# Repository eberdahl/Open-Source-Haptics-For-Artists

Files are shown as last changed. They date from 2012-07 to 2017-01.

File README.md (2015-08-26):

Open-Source-Haptics-For-Artists
-------------------------------
This website provides a venue for users to share open-source software and hardware haptic technology with one another. While the focus is primarily on artistic applications, we believe that mutual collaboration can help the field of haptics progress most rapidly in art, science, and technology. 

This git repository has been created via a collaboration between the Technical University of Berlin, the Cardiff School of Art & Design, and Stanford University.  If you develop some nice contributions, please let us know, and we would be happy to incorporate them.

Current maintainers:
Edgar Berdahl (eberdahl@ccrma.stanford.edu)
and
Alexandros Kontogeorgakopoulos (akontogeorgakopoulos@cardiffmet.ac.uk)

Main website:
http://www.openhaptics.org/

To use OSHA, install git and then run the following command:

git clone --recursive https://github.com/eberdahl/Open-Source-Haptics-For-Artists.git

cd Open-Source-Haptics-For-Artists

To update this repository, run the following from the root directory:

git pull

git submodule update

In general, please use the Google group for asking questions:
https://groups.google.com/group/open-source-haptics-for-artists

I have decided to officially support the Max/MSP objects and the Synth-A-Modeler objects, once I deliver them.  I STRONGLY RECOMMEND USING MAX/MSP OR SYNTH-A-MODELER.  However, I understand that people might be interested in using the older pd or Chai3D code, so I am including the source for them as starter code.

Notes on software
-----------------
- Currently the Max/MSP support is the most fleshed out, including testing the concept of using capacitive sensing to enable or disable the force feedback.  To use the Max/MSP patches, you will to put the palette folder in the path.
!!!**  Remember to set the "Signal Vector Size" to 1  **!!!

Notes on hardware
-----------------
By default the motor controller sets up 
- D4: Direction control of Motor A 
- D5: PWM speed control of Motor A 
- D6: PWM speed control of Motor B 
- D7: Direction control of Motor B 
- A0: Current sense of Motor A 
- A1: Current sense of Motor B 

So pin D5 and D6 on Arduino are ATMega328 pins correspond to
D5 --> PD5(T1)
D6 --> PD6(AIN0)

Best,
Edgar Berdahl
March, 2012 and updated July, 2012 and October, 2012

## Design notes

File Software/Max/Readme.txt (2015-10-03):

Max/MSP support is implemented via the HSP ("Haptic Signal Processing") package

Contributors: Edgar Berdahl and Alexandros Kontogeorgakopoulos

For Max/MSP 5, 6 and 7.

It has been tested on Mac OS X with Intel processors.  The FireFader works in Windows (but to use the NovInt Falcon device in Windows, someone would need to recompile the external object "np_nifalcon.mxo").

VERY IMPORTANT
--------------
1. Add the "palette" folder to the paths for Max/MSP 5, and then try out the examples in the models folder.
2. Set the "Signal Vector Size" to 1 in the DSP Settings.
3. Set the "Event Interval (ms)" to 1 and the "Scheduler Interval (ms)" to 1 in the Preferences.

MAKE SURE THAT YOU’RE OPENING THE CORRECT HAPTIC DEVICE
-------------------------------------------------------
1. First make sure that the FireFader (or whatever haptic device you want to use) is unplugged.
2. Open the FireFader~.maxpat file in Max.
3. Click on the ‘print’ message and look in the Max window to see what letter Max is associating with each serial device that Max is finding.  The haptic device that you want will not be here.
4. Close FireFader~.maxpat.
5. Wait five seconds, plug in the haptic device and then open FireFader~.maxpat again, and then wait fifteen seconds.
6. Click on the ‘print’ message to list what letter Max is associating with each serial device that Max is finding.  The new serial port entry corresponds to your device.
7. Make sure that the second argument to the ‘serial’ object in FireFader~.maxpat matches the letter of the device.
8. By this point, you should also see some meaningful output inside the number boxes below representing the ‘position’ of the device.

You will need to follow some similar procedure in concept to this to open the Falcon.

Note: If the FireFader is plugged in to a Mac before the Mac is booted up, it will likely show up with a different letter (e.g. ‘a’) once the computer boots up.  This can be fixed by unplugging it, waiting 5 seconds, plugging it in again, and waiting 15 seconds.

TROUBLESHOOTING
---------------
If it isn’t working the way you expect, make sure that you precisely followed each of the above steps.  Then, if there are still difficulties (such as models not feeling the way that you think they should feel), close all other applications, reboot the computer, and run only Max.  Finally, it can also help (particularly if there are some animated GUI objects in the Max patch) to minimize the Max patch so that Max isn't running any drawing routines.  The reason for this is that the graphics events are running at the same priority level as the serial object.

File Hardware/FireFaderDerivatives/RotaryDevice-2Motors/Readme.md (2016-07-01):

This design is the same as the FireFader except that in place of fader A, a rotary motor with rotary encoder is connected.  In place of fader B, a second rotary motor with rotary encoder is connected.  For those motors, we have the same power connections as with the motorized fader.

This is how it works using two motors:

We could use one hardware interrupt per motor.  In this case, we will have to rewrite the interrupt handlers CountA() and CountB() to do the logic for each motor separately.  In that case, whenever an interrupt is triggered, we need to manually check the value of the other phase (connected to some other digital input pin that doesn’t support hardware interrupts) and then figure out how to do the right state machine logic.

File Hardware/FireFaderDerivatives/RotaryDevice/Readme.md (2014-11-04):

This design is the same as the FireFader except that in place of fader A, a rotary motor with rotary encoder is connected.  For that motor, we have the same power connections as with the motorized fader.

However, the sensing works differently.  Instead of connecting an analog voltage to pin A2, we instead use two digital inputs that are 90° out of phase with each other.  “Phase A” of the rotary encoder is connected by a white wire to pin D2, which supports hardware interrupts.  “Phase B” of the rotary encoder is connected by a green wire to pin D3, which also supports hardware interrupts.  By typing a hardware interrupt to each of the encoder phases, we can get the maximum resolution of the measurement.  Power (i.e. 5V) and ground (blue wire) are also connected to the encoder to power its circuitry.

In summary, for the rotary motor we have the following:

blue-ground

white-channel A

red-5V

green-channel B

I recommend using rotary motors that have at least 400 counts per revolution to get the most accurate sensing.  In the current project, I’m using motors that have about 1000 counts per revolution.  See the datasheets stored inside the directory Encoder-Datasheets for information on some common rotary encoders such as HEDL 5540 and HEDS 5540.

To hook up a second rotary motor:

* We could use one hardware interrupt per motor.  In this case, we will have to rewrite the interrupt handlers CountA() and CountB() to do the logic for each motor separately.  In that case, whenever an interrupt is triggered, we need to manually check the value of the other phase (connected to some other digital input pin that doesn’t support hardware interrupts) and then figure out how to do the right state machine logic.

* Or we could try to connect the second motor’s encoder phases instead to digital inputs 0 and 1, which also support hardware interrupts.  This will give us higher resolution measurements overall; however, I believe that it will interfere with the USB communication, so try it at your own risk!  You may not be able to connect it to the Max models at all!

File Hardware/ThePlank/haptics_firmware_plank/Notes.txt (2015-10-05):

To use The Plank with the Open-Source-Haptics-For-Artists repository, it's necessary to have a way
to disable the force feedback if the user isn't touching the device.  This could be accomplished
by using the FSR as a sensor to check if the user is touching the handle; however, then further 
modifications would need to be made to this firmware and the circuit.  Instead, I recommend 
adding a capacitive sensor to the device handle.  This way, the device can be played with a light touch.

This can be achieved by:
• taking a piece of copper tape and soldering a stranded wire to it (use some solder flux to 
  make this easier)
• strip the other end of the wire and tin it if using a breadboard
• use a piece of (electrically nonconducting) double-stick tape to attach the piece of copper tape
  to the device handle
• build the circuit as shown in Figure 5 of the Computer Music Journal article
  "The FireFader: Simple, Open-Source, and Reconfigurable Haptic Force Feedback for Musicians"
  replacing "Motor A."  Instead of connecting the 2nd pin of the potentiometer to Arduino pin A2,
  connect the voltage output of the Hall-effect sensor to Arduino pin A2.
• Repeat the same procedure analogously for a second Plank motor as "Motor B."

USE THE ARDUINO MICRO FOR BUILDING THIS WITH THE MOTOR DRIVER http://www.gravitech.us/2mwfecoadfor.html, ALSO AVAILABLE THROUGH MOUSER.

// Anyone trying to use The Plank with Open-Source-Haptics-For-Artists should first try the 
// Synth-A-Modeler models, which are compatible with this firmware.  To do this, run 
// 'make jackqt' inside the SaM subdirectory of the part of the repo
// https://github.com/eberdahl/Open-Source-Haptics-For-Artists/tree/master/Software/Synth-A-Modeler
// and visit https://ccrma.stanford.edu/wiki/SynthAModelerFireFaderLab for additional instructions
// to set that up.
// 
// After getting those working, then try the models in Max using the FireFader~ object to interface
// with the firmware--see
// https://github.com/eberdahl/Open-Source-Haptics-For-Artists/blob/master/Software/Max/Readme.txt

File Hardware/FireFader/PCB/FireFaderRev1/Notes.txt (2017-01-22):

The FireFader is a haptic device, whose electronics can be easily realized using a simple breadboard.  In our opinion, the PCB is not really part of the original concept of the FireFader.  However, some folks have been asking for the PCB design, with the potential for creating other derivative designs, which is a nice possibility, so the PCB version is posted here as well.

This design is specifically for the ALPS RSA0N11M9A06.  This specific part might no longer be available new; however, new ALPS parts with a very similar part number (that to us are indistinguishable) appear to be drop-in replacements.

Additional notes:
• The schematic part symbol in the .brd file is not accurate; however, the manufactured board has verified as working.
• There might potentially be other issues with the ALPS-motorfader.lbr which was found on the Internet and whose footprint had to be modified in order to generate correct Gerber files.

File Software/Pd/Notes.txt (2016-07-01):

PD IS NOT OFFICIALLY SUPPORTED !!!!!

If there are any compiled SaM patches here, in order to use them, you will have to add two_examples-FireFader to the pd path.

The pure data patches are not currently maintained for these reasons:
 ¥ The Max/MSP scheduler is able to run a little bit faster than the Pd scheduler, so the feedback control works a little bit better.
 ¥ It's harder to build physical models directly in pd because pd requires you to manually insert all of the single sample delays separately (so the patches don't look as nice).
 ¥ We don't have a particularly nice collection of models that are in good shape to be presented.

If you really need to use pd, drop us a line and we will see what can be done about it!

Cheers,
Edgar Berdahl

PS. In pd, try adding the following to the startup flags to decrease the delay for haptics:
-rt -sleepgrain 1
(or maybe -rt -sleepgrain 2 if the previous crashes pd on your machine)

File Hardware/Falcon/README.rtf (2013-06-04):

Although the Falcon is not an open-source hardware device, it has been hacked. Thanks to Kyle Machulis for taking the lead on writing the driver for it! The driver source is included here for those who wish to compile it. However, a compiled version of the Max/MSP 5 external for OS X (Intel) "np_nifalcon.mxo" has been installed into the Software:MaxMSP:palette directory and might work for you.

A very good list of references on the Falcon hardware can be found here:
http://qdot.github.io/libnifalcon/documentation.html

This reference looks particularly good:
http://docs.nonpolynomial.com/libnifalcon/pdf/CharacterizationOfANovintFalconForApplicationAsARobotManipulator.pdf

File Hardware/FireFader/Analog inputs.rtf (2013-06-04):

A0: Current sense of motor A
A1: Current sense of motor B
A2: Position of Motor A
A3: Position of Motor B

A6: FSR for Plank motor A (CiiD only uses a single Plank and puts this between A6 and A4 and uses the Arduino-internal pull-down resistor)

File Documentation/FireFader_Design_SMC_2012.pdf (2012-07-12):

3URFHHGLQJV RI WKH WK 6RXQG DQG 0XVLF &RPSXWLQJ &RQIHUHQFH &RSHQKDJHQ 'HQPDUN -XO\

## The FireFader Design: Simple, Open-Source, and Reconfigurable Haptics for Musicians

Edgar Berdahl
Audio Communication Group
Technical University of Berlin Germany

Alexandros Kontogeorgakopoulos Cardiff School of Art and Design Cardiff, Wales
United Kingdom

ABSTRACT

The FireFader is a simple haptic force-feedback device that is optimized for introducing musician to haptics. It has one degree of freedom and is based upon a mass-produced linear potentiometer fader coupled to a DC motor, also known as a “motorized fader.” Lights are connected in parallel with the motor to help visually communicate the strength of the force. Compatible with OS X, Linux, and Windows, the FireFader consists of only open-source hardware and software elements. Consequently, it is also relatively easy for users to re-purpose it into new projects involving varying kinds and numbers of motors and sensors.
An open-source device driver for the FireFader allows it to be linked to a laptop computer via USB so that the computer can perform the feedback control calculations. For example, the laptop can simulate the acoustics of a virtual musical instrument to calculate the motor force as a function of the fader position. The serial connection over USB causes delay of the control signal, but the serial connection facilitates easier programming via the laptop, and the force feedback can be disabled when the user is not touching the fader. Some new devices derived from the FireFader design are presented.

### 1. INTRODUCTION

### 1.1 Overview

While traditional musical instruments provide haptic touchoriented feedback, this kind of feedback is lacking in many digital musical instruments. This is one reason why the community is generally interested in endowing new digital musical instruments with haptic feedback. Haptic feedback can take many forms [1], and one important form is force feedback, which allows a user to interact kinesthetically with a virtual mechanoacoustical system.
While considerable research has been carried out on force feedback for musical systems [2, 3], it has not trickled down into systems that are widely available to musicians. One of the main reasons for this is that most prior

Copyright: !c 2012 Edgar Berdahl et al. This is an open-access article distributed under the terms of the Creative Commons Attribution 3.0 Unported License, which permits unrestricted use, distribution, and reproduction in any medium, provided the original author and source are credited.

force feedback systems were too expensive for most musicians. For example, the force-feedback devices from Ergos Technologies are designed with the highest quality musical applications in mind: the devices have a position resolution of <1µm, mechanical bandwidth of 20kHz, and maximum force of up to 200N. ¹ We would love to teach workshops with them; however, they cost tens of thousands of Euros, so they are beyond the cost of most musicians’ budgets [2].
Force-feedback devices from Sensable Technologies are less expensive. For example, the least expensive device from Sensable is the Phantom Omni, which costs about $1000 USD. However affordable this price may or may not be, the devices from Sensable are designed with medical applications in mind, such as surgery, and a musician on stage may not be so interested in sitting at a table and performing with a pen-like object.
For instructional purposes, several universities have made simpler haptic force-feedback devices that are less expensive [4]. The series of “Haptic Paddles” are single degreeof-freedom devices based upon a cable connection to an off-the-shelf DC motor. However, such designs are problematic because of the unreliable supply of surplus highperformance DC motors [5]. We ourselves contacted four companies selling DC motors with integrated sensors, and we could not find a low-price motor of this type that was always available new. Surplus motors can be obtained, for instance from stock of old hard disks [6]; however, removing the motors from the disk drives themselves requires some additional work. New, identical DC motors can be ordered from companies such as Maxon motors, but they tend to cost more than $100 or even $200 USD each when they include a position sensor. ² In contrast, the iTouch device at the University of Michigan instead contains a voice-coil motor, which is hand-wound by students [5]. However, making a large number of devices is time intensive, and the part specifications are not available in an open-source hardware format.
In our own prior work, we have used the least expensive general-purpose force-feedback robotic arm called the NovInt Falcon. Over the past several years, its price has ranged between $100 USD and $250 USD. The Falcon is designed primarily for gaming, so it is inexpensive and is accessible to musicians [7]. Conveniently, it has an open-

1 http://acroe.imag.fr/ergos-technologies
2 http://www.maxonmotor.com/

source driver compatible with Mac OS X, Windows, and Linux [8]; however, the appearance and size of the device can be less appealing to musicians. Also in our own prior work, we have alternatively emphasized that radically different actuator configurations can be artistically interesting, such as the haptic drum, which uses a woofer to actuate a drumstick [9]; however, the Falcon’s geometry cannot easily be modified because of the complex interconnections of the cables and other parts.
Standardized configurations are useful as they can be employed in and abstracted to a wider variety of applications, and indeed this consideration has influenced the FireFader’s design.

### 1.2 Requirements

In consideration of prior work and our own experiences, we arrived at the following requirements for the device design. The device should

- implement standardized force-feedback control with collocated sensing,
- be relatively inexpensive yet still perform well enough for intriguing musical applications,
- have access to high-quality audio converters,
- be compatible with OS X, Linux, and Windows,
- be controllable via double-precision floating-point physical models [10],
- be easy to assemble,
- be reconfigurable,
- allow additional sensors to be incorporated with ease,
- inspire musicians with its design,
- be simple enough that students can understand and reconfigure it, and
- consist of open-source hardware and open-source software elements.

### 2. HARDWARE DESIGN

### 2.1 Motor

To keep the cost down, we decided to center the design about a motorized fader, which is a linear potentiometer coupled to a DC motor. Motorized faders are mass-produced by multiple companies, including ALPS Electric and Penny + Giles, so the competition can tend to drive down the price. Furthermore, motorized faders can be found in many audio mixing consoles, so most professional musicians are familiar with them already. For that reason, we thought that musicians might on average be more interested in force-feedback interaction with a motorized fader than with something more foreign-looking like a haptic paddle, and we have noticed this trend among our own students.

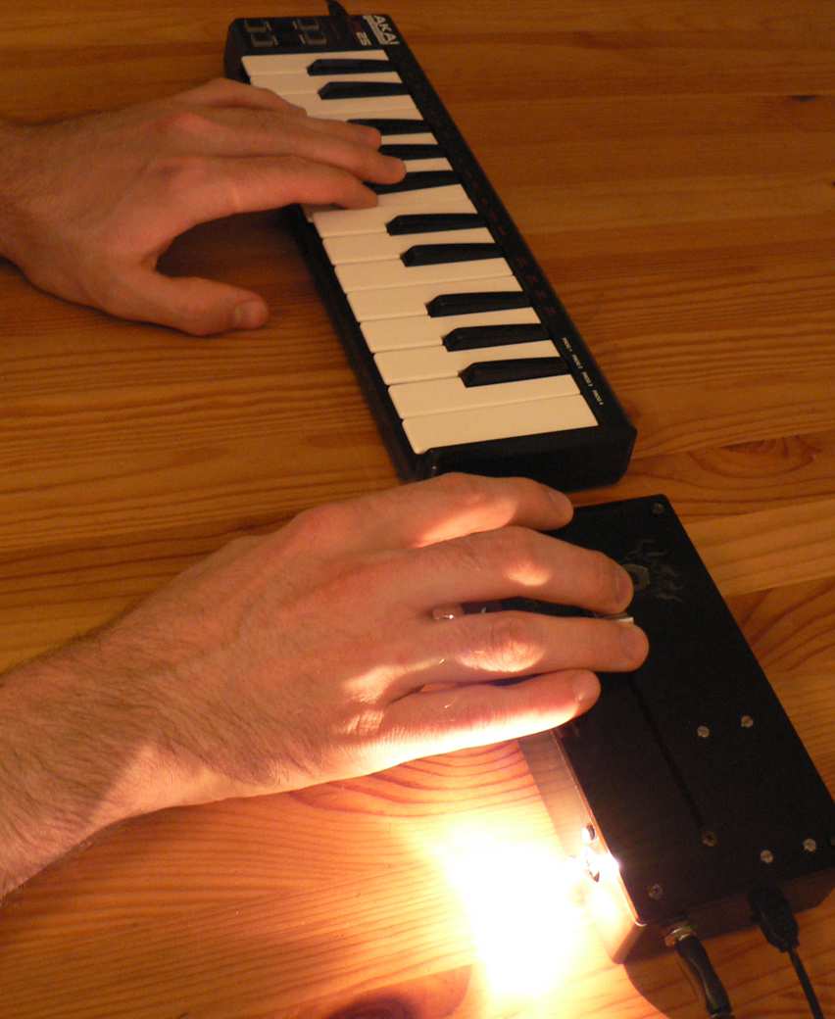
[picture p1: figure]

Figure 1. FireFader (below) with MIDI keyboard (above)

We compared several different faders, and we eventually decided to primarily use a motorized fader from ALPS, which currently can often be purchased at a price of about $25 USD each new.
We would like to note that the idea of using a motorized fader for new musical applications is not new. Bill Verplank has maintained a stock of them in the laboratory at CCRMA for several years, and other human-computer interface researchers have experimented with them [11], even for audio applications [12–14]. However, our design differs due to the availability of new open-source hardware, an expanded sensing design, and we agree with the philosophy that the user should be able to use powerful floating point computations for the feedback control, to prevent getting distracted by a need to write efficient firmware.

### 2.2 Concept

For musical applications, it could be interesting to combine the FireFader’s force feedback with other more common user interfaces. In other words, building a keyboard with all force-feedback keys is very impressive [15]; however, one can still obtain interesting interactions with the combination of a single degree-of-freedom force-feedback device and a standard MIDI keyboard. Figure 1 shows a FireFader prototype (below) and a small MIDI keyboard (above).

### 2.3 Lights

While force feedback can easily change the nature of interaction from a performer’s perspective, in many situations the audience might not perceive the presence of the force feedback. Thus, we thought the device might benefit from a method for communicating the force level to the audience, in line with the concept of multisensory simulation with coherent multimodal feedback [16]. A bright light helps suggest the metaphor of fire, suggesting power,

3URFHHGLQJV RI WKH WK 6RXQG DQG 0XVLF &RPSXWLQJ &RQIHUHQFH &RSHQKDJHQ 'HQPDUN -XO\

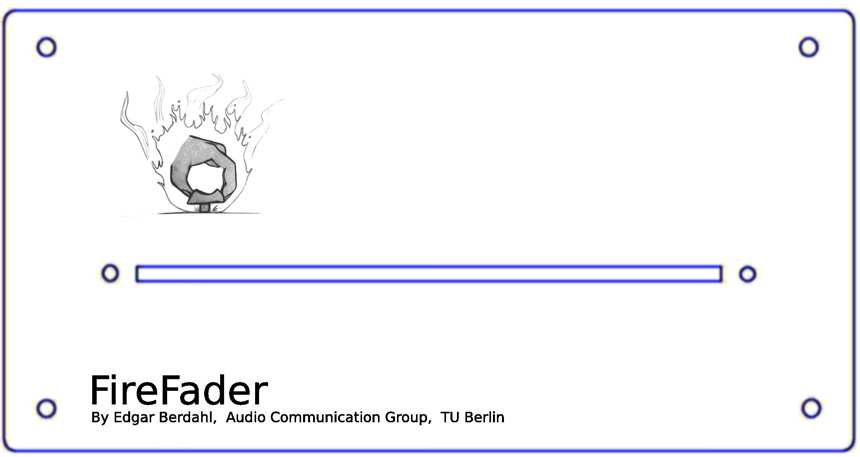
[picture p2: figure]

Figure 3. Specification image for top plate for one fader

excitement, and extraordinariness. This explains why we named the device the FireFader, which helps to further distinguish it from other user interfaces that lack active haptic feedback.
We employed a light to indicate the force level for each fader. Even if the audience would not realize that the lights communicated the force level, the lights could probably at least draw attention to the force itself. Furthermore, we thought this feature might seem exciting and inspiring to musicians, emphasizing the distinction between a common digital musical interface and an interface with force feedback.
We experimented with over 50 different lights in order to find a bright light that looks appealing over the motor driver’s dynamic range. One good solution is a 5W Halogen lamp, which has a slightly yellowish tinge to it as seen in Figure 1. Other lights may be less delicate, such as a 20mm LED in series with a 1W 100 ohm resistor, or a 12V LED replacement lamp.

### 2.4 Enclosure

We wished to provide an open-source method for creating enclosures for the FireFader. Laser-cut parts are appealing due to low cost, ease of reconfigurability, and the wide variety of materials available for laser cutting. While it is possible to build entire enclosures using laser cutting methods, ³ these enclosures tend to involve a lot of screws and look unusual due to the inability to laser-cut threaded screw holes. For this reason, we decided to laser-cut only the top plate for the enclosure, including the long groove for the fader itself, and to fix the top plate to part of a standard plastic box. Figure 3 shows the open specification image for the single-fader top plate that matches the Strapubox 2003 SW bottom with outer dimensions 160mm by 83mm by 52mm. Using open-source software such as Inkscape, the top plate specification could easily be modified to fit another mass-produced box. The final enclosure design is shown in Figure 4, which incorporates two motorized faders.

### 2.5 Electronics

The electronics are based around the Arduino Nano 3.0 microcontroller, which plugs directly into the 2MOTOR

3 http://support.ponoko.com/entries/20344437-laser-cut-project-boxtutorial

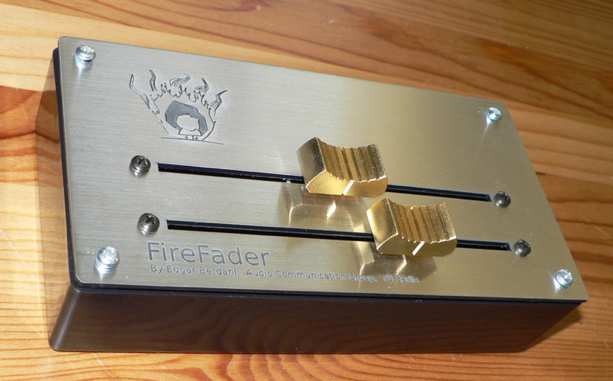
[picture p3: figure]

Figure 4. Final FireFader enclosure design incorporating two motorized faders

FireFader

ADC

Serial interface

USB

Laptop

Arduino Nano

FTDI

or other application

Pd, Max/MSP, Chai3D,

Floating− point

calculations

Motor Driver

PWM

Figure 5. Signal flow for the control loop

H-bridge add-on board. The schematics for both of these boards are available on Gravitech’s website. ⁴ The interconnecting wires for the remaining components are given in the schematic for the FireFader (see Figure 2).

### 3. SOFTWARE DESIGN

### 3.1 Signal Flow

The FireFader communicates with a laptop in order to gain access to fast real-time floating point computation and high-quality audio converters. The usage of the laptop also eases programming the FireFader because code efficiency is less of a concern.
The signal flow describing how the FireFader and laptop work together is shown in Figure 5. First the Arduino measures the position of the fader via the ADC. Then the Arduino uses its FTDI chip to send the measured position to the laptop over a serial interface provided by USB. The laptop runs an application to control the FireFader. Currently Max/MSP, Pure Data (pd), Chai3D, and a generic application are supported. This application receives the position of the fader and computes a reaction force. The application sends the reaction force over the serial interface via USB to the Arduino, which uses the 2MOTOR H-bridge board to exert the reaction force via the motor (see Figure 5).

### 3.2 Arduino Firmware

An Arduino firmware program runs on the Arduino to facilitate the signal flow shown in Figure 5. A main loop on

4 http://www.gravitech.us/

3URFHHGLQJV RI WKH WK 6RXQG DQG 0XVLF &RPSXWLQJ &RQIHUHQFH &RSHQKDJHQ 'HQPDUN -XO\

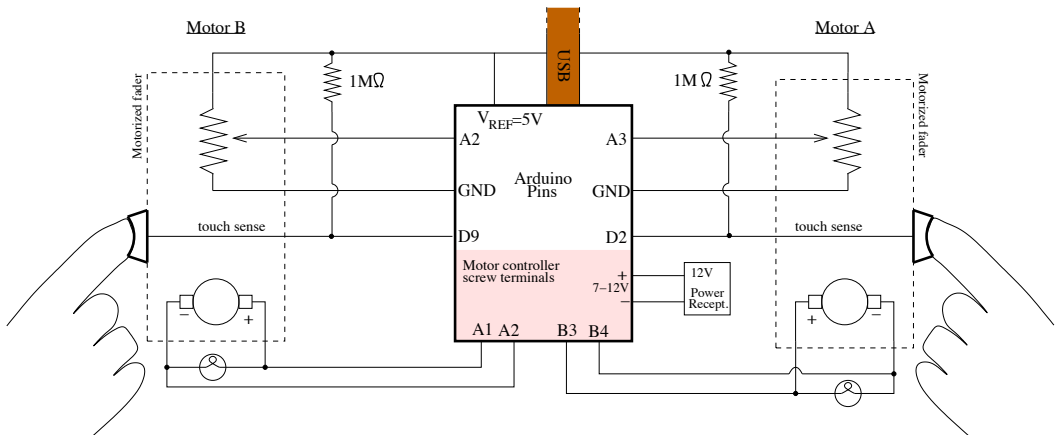
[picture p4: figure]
Power Recept.; VREF; touch sense; Motor A; GND; Motor controller screw terminals; USB; Motorized fader; Arduino Pins; Motor B

Figure 2. FireFader schematic for controlling two motorized faders and two halogen lamps

the Arduino repeats the following steps over and over. We describe them in detail here because the explanation could be helpful for users who want to modify the firmware when reconfiguring the device:

1. While input serial data from the laptop is available, read it in, and write the most recent force commands to the PWM pins for controlling the motors.
2. For each fader, sample its analog input multiple times and average the result to obtain an estimate of its position.
3. Sample the analog inputs for additional ADC pins, to be used with any generic sensors, while averaging the results.
4. Perform capacitive sensing for each of the faders.
5. Send the sentinel character 255 over the output serial interface to indicate that a new packet of information is available.
6. Send the position of each fader, clipping it to the range 0 to 254 to avoid confusion with the sentinel.
7. Send the values from the other sensors, clipping each value again to the range 0 to 254 to avoid confusion with the sentinel.
8. Send the low-pass filtered capacitive sensing value from each fader, clipping it to the range 0 to 254.
9. Wait for approximately 100 µs.

The wait statement helps prevent the serial bus from getting overrun with data. To slow down the firmware for debugging, the wait statement can be changed to values such as 100 ms or 1 s.

### 3.3 Host Software on Laptop

3.3.1 Custom Application

Physical models for controlling the FireFader can be generated using the Synth-A-Modeler software package [17].

It generates Faust DSP code that can be compiled into a custom application that accesses the FireFader directly via USB and produces output audio via Jack [18]. However, some users may prefer to employ the FireFader from within other common sound synthesis environments. For this reason, we have provided sample driver code for Max/MSP and Pure Data (pd).

3.3.2 Configuring the Feedback Control Delay

In order for the FireFader to work well, the feedback control delay needs to be short, yet each element in the feedback loop contributes some delay. We have optimized the delay of the elements in the loop as best possible subject to the low-cost design. The application running on the laptop contributes some delay, so we provide some tips here for reducing that delay.
In Max/MSP and Pure Data (pd), the position of the Fire-Fader is received as an event. Thus, events need to be processed frequently, which can be configured by adjusting the scheduler. In Max/MSP 5 the scheduler interval can be set to 1ms in the Preferences window under “Scheduler.” In Pure Data (pd), the scheduler interval can be set using the startup switch “-sleepgrain 1” although under some conditions better performance can be achieved using “-rt -sleepgrain 1” to also enable real-time scheduling if available on the operating system.
Finally, it is essential to set the default value for the FTDI chip’s latency timer to 1ms. This cannot be set by the Arduino firmware, but it can be set via the FTDI driver on the laptop. Accordingly, it is essential to follow instructions ⁵ for setting the FTDI latency. Otherwise, the serial buffer on the FTDI chip on the Arduino may not be flushed as often, increasing the latency of the force feedback by as much as 16ms or more.
Under OS X with Max/MSP 5, we measured the roundtrip control delay to be roughly 3.5ms on average. This is about the same as the latency for the open-source NovInt Falcon driver, which also uses a serial link over USB via an FTDI chip. Performance under Pure Data (pd) has been

5 http://projectgus.com/2011/10/notes-on-ftdi-latency-with-arduino/

3URFHHGLQJV RI WKH WK 6RXQG DQG 0XVLF &RPSXWLQJ &RQIHUHQFH &RSHQKDJHQ 'HQPDUN -XO\

good on the Beagle Board xM but not as good under OS
X. We are continuing to debug the performance in pd for OS X.

### 4. TOUCH SENSE ENABLE

If feedback control with a large gain is desired, which can be the case when modeling a very stiff spring or strong damper, then the force feedback can cause a haptic device to become unstable, especially if the delay around the control loop is significantly long. Instability is a potential problem because it can damage the device. However, a user generally provides a stabilizing influence when touching a device [19].
Thus, for devices such as the FireFader, which are subject to relatively long feedback control delays, it is a good idea to only enable the force feedback when the user is touching the fader knob. This “touch sense enable” feature allows for programming interactions with larger gains, because the feedback is disabled when the user releases the fader knob. The feature can be implemented via capacitive sensing of the “touch sense” pin that is electrically connected to the fader knob with a little help from the firmware and the 1MΩ pull-up resistor (see Figure 2).

### 5. TESTING

### 5.1 Instructional Prototypes

We evaluated the FireFader from an instructional perspective using five prototypes. Students in the Music 250A course at Stanford University used the prototypes to complete a musical design-oriented exercise in October 2011: https://ccrma.stanford.edu/wiki/250a Haptics Lab 2011

The laboratory exercise was motivated by a previous exercise by Bill Verplank [4] adapted for the new device. In the new exercise, students programmed by specifying physical models instead of writing plain C code [20]. The results indicated that students could program much more complex designs using physical modeling than when writing plain C code.

### 5.2 Example Projects

Example projects have provided more opportunity to refine the FireFader’s design. Figure 6 shows the Sound Flinger by Chris Carlson, Eli Marschner, and Hunter Mc-Curry. The four faders allow users to interact with a virtual mass sliding along the edges of a square, while the position of the mass set the angle at which an audio input was reproduced within a room [21].
For PROJECT SQUEEZE, Joel Sadler and Shruti Gupta constructed a single degree-of-freedom exoskeletal haptic pincher out of the FireFader parts [22]. The pincher was made primarily out of laser-cut acrylic, including a piece which links the fader handle with the thumb (see Figure 7). Edgar Berdahl constructed String-U-Topia using an early FireFader prototype to implement a plucked interaction with a triplet of virtual strings [23].

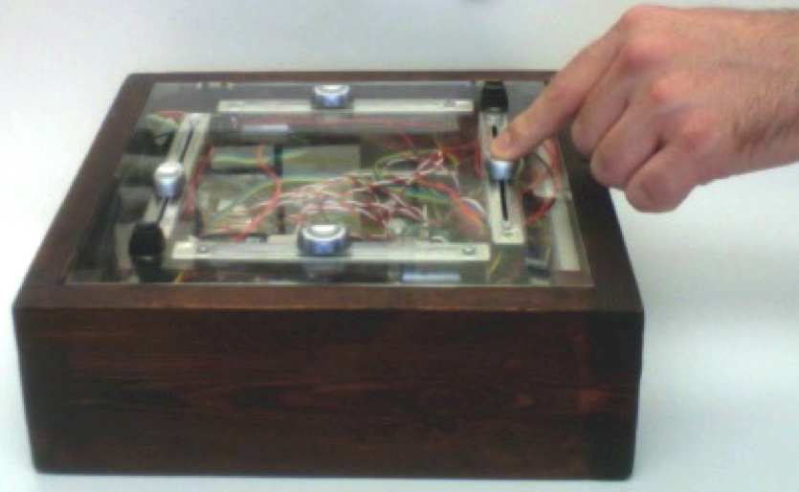
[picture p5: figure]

Figure 6. The Sound Flinger

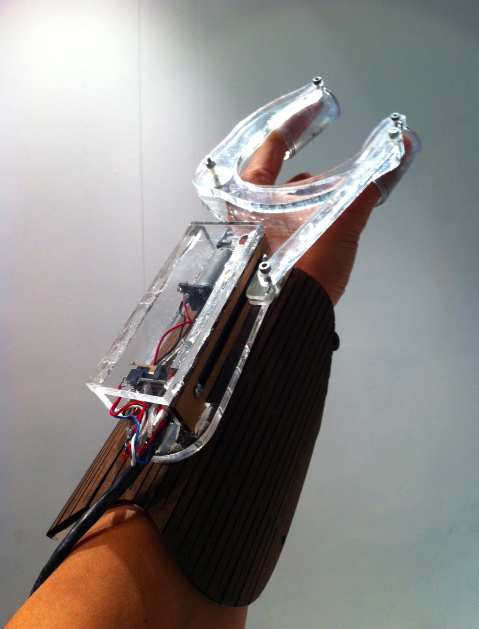
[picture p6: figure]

Figure 7. Exoskeletal haptic pincher from PROJECT SQUEEZE

The design of the light can also be important. We show a few frames from a video clip of an older prototype in Figure 9 to further illustrate the effect of the lighting.

### 6. CONCLUSIONS

The design of the FireFader has been an iterative process and was first announced in an abstract published by the Acoustical Society of America [24]. This paper serves to provide detail on the design, how musicians have been using it, and the full open-source disclosure of the hardware and software.
The FireFader hardware components, Arduino firmware, pictures, and drivers for Max/MSP, Pure Data, Chai 3D, and sample generic application can be found in the archive:

https://ccrma.stanford.edu/˜eberdahl/FireFader.zip
The device is simple, open-source, and reconfigurable, so we hope that it will appeal to musicians as well as the broader DIY community. We have started a Google Group for providing support for the platform and generally trying to galvanize the DIY community:

http://groups.google.com/group/open-source-haptics-for-artists
We believe that the FireFader is the only completely open-source hardware and software system for building

3URFHHGLQJV RI WKH WK 6RXQG DQG 0XVLF &RPSXWLQJ &RQIHUHQFH &RSHQKDJHQ 'HQPDUN -XO\

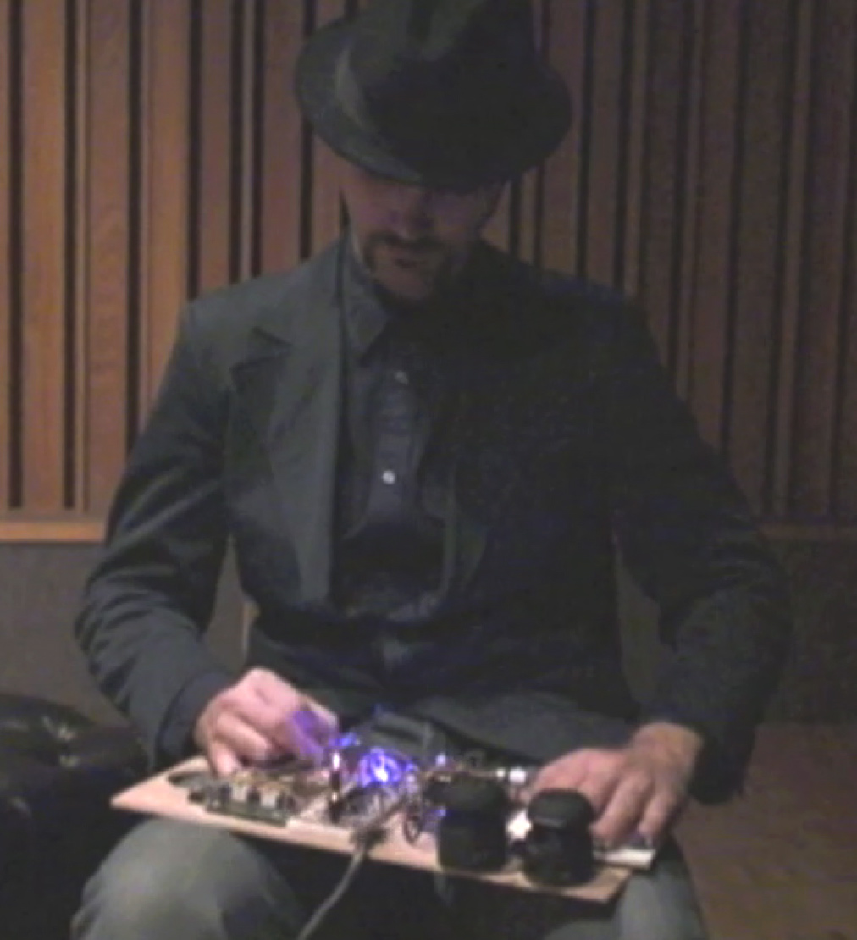
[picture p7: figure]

Figure 8. String-U-Topia

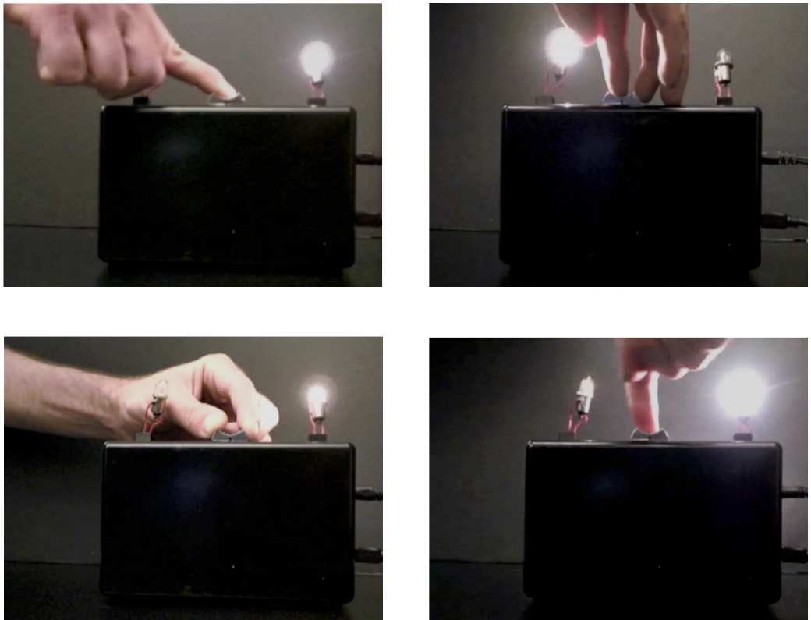
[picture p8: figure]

Figure 9. An older prototype of the FireFader at work

haptic musical instruments with force feedback. It is relatively inexpensive, with the total cost of the parts adding up to about $150 USD for two faders. The capacitive sensing feature allows for the force-feedback to be enabled only when the user is touching the knob, allowing for implementing force feedback with relatively large control gains despite the relatively long feedback control delay of 3.5ms on average.
Finally, the FireFader is so small and convenient that we plan to teach workshops with it to introduce more members of the community to what force-feedback has to offer for them. In future work, we will create a library of physical models for controlling the FireFader to help teach users how to integrate force feedback into their own musical instrument designs.
A. ESTIMATING DOWNWARD PRESSURE

Adding motors is more expensive than adding sensors. In this appendix, we describe how to inexpensively sense the downward pressure that the user applies to the fader.
In fact, if one covers the fader knob with resistive fabric such as sold by EeonTex and presses on the knob [25], an analog signal related to the downward pressure is already

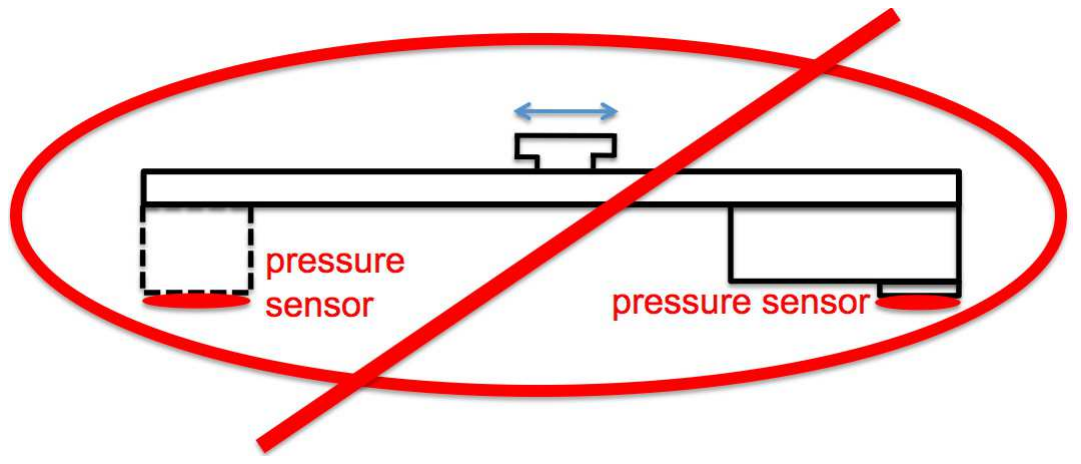
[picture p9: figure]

Figure 10. Motorized fader with FSRs under each end

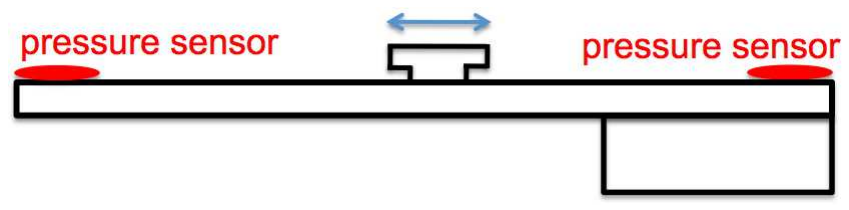
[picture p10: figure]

Figure 11. Motorized fader with FSRs placed on top

obtainable via the capacitive sensing circuit (see connections to pin D9 in Figure 2). However, we found this sensing approach to be noisy, and it only provided a small dynamic range.
We made further experiments using inexpensive force-sensing resistors (FSRs). At first we tried placing an FSR underneath each end of the motorized fader as shown in Figure 10, mounting the entire fader on top of the project box (not shown). The idea was to combine the sensed signals to estimate the downward pressure applied by the finger. However, we found that the measurements to be marginal, perhaps due to the compliance of the motor mounting.
Next we tried placing the FSRs on top of the motorized fader as shown in Figure 11, so that they could be sandwiched in between the motorized fader and the project box. We found this approach to work much better.
Figure 12 shows all of the sandwich elements, including also a white piece of compliant double-stick tape and a spring-loaded piece of acrylic to preload the FSR. When the user pushed downward on the fader knob, the fader pulled downward on the screw in the center (see arrow in Figure 12) to reduce the preload on the FSR. The orientation of the sandwich elements is shown in two profiles in Figure 13.
The dynamic range of the sensor signal needed to be increased in order to obtain a high-quality measurement. Figure 14 shows the circuit we used to obtain a gain of 1+(Rf /Rg)=8. The trimpot Rs adjusted the offset voltage for the sensor signal, and it had a similar effect to changing the tightness of the four preload-adjustment screws (see Figure 12). In a more refined implementation, the trimpot could probably have been replaced with fixed resistors and the calibration performed using only the four preload-adjustment screws.
To estimate the downward pressure applied by the user, the sensed parameters were combined. FSRboth described the sum of the two FSR measurements:

FSRboth[n]= FSR1[n]+ FSR2[n]. (1)

3URFHHGLQJV RI WKH WK 6RXQG DQG 0XVLF &RPSXWLQJ &RQIHUHQFH &RSHQKDJHQ 'HQPDUN -XO\

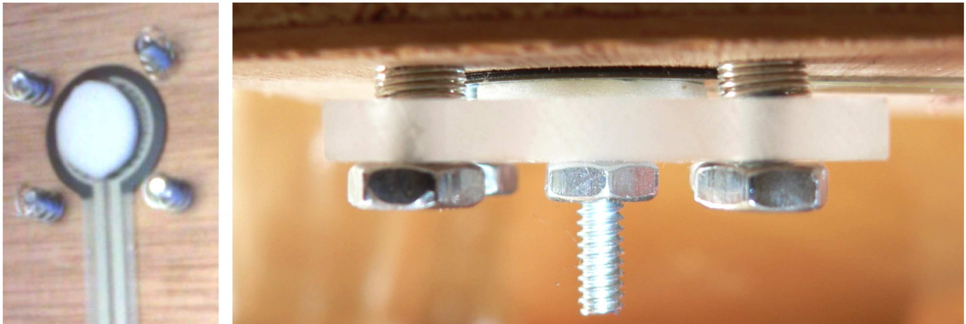
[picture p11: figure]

Figure 13. Sandwich elements shown with motorized fader removed (left: bottom view also with acrylic removed, right: side view with acrylic)

pFSR[n]= ! | 0, | if ccapsense[n] <cthresh
FSRboth[ntouch] − FSRboth[n], | otherwise | (2)

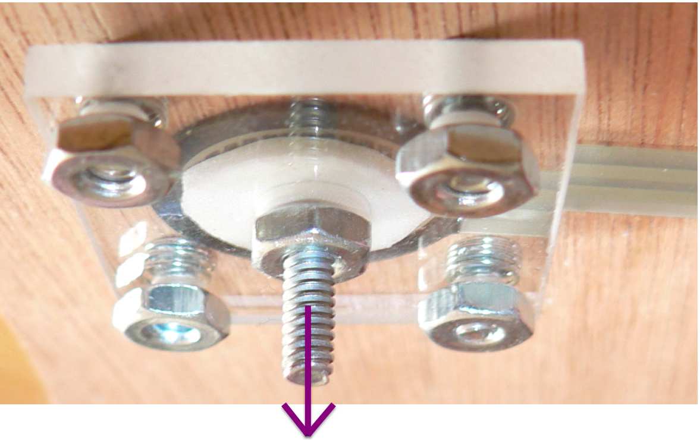
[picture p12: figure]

Figure 12. Sandwich elements with arrow showing the direction of the force that the fader end can exert on the sandwich

With the amplification, the FSR signals were subject to noticeable hysteresis [26]. However, we could reduce the effect of the hysteresis using the capacitive sensing signal ccapsense[n] to keep track of when the user was touching and releasing the fader knob (see (2)— cthresh was a capacitive sensing threshold parameter to be calibrated depending on the electrical properties of the surrounding environment, and ntouch +1 indicated the most recent time index at which the signal pFSR[n] became non-zero). Finally, by forming a linear combination of these two signals, we obtained a relatively inexpensive estimate of the downward force.

ptotal[n]= α · pFSR[n]+ β · ccapsense[n], (3)

where α > 0 and β > 0.

B. REFERENCES
[1] D. Birnbaum, “Musical vibrotactile feedback,” Master’s thesis, McGill University, Montreal, Canada, October 2007.
[2] J.-L. Florens, C. Cadoz, and A. Luciani, “A real-time workstation for physical model of multi-sensorial and

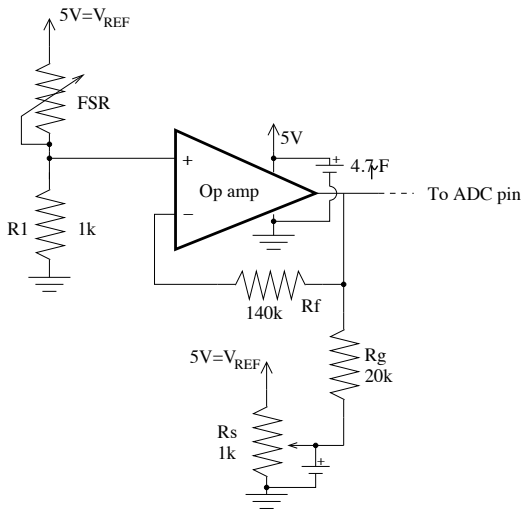
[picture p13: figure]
5V=VREF; FSR; To ADC pin; Op amp

Figure 14. Operational amplifier circuit increases the dynamic range of FSR sensor signal while allowing the DC offset to be adjusted

gesturally controlled instrument,” in Proceedings of the International Computer Music Conference, Ann Arbor, MI, USA, July 1998.

[3] C. Cadoz, A. Luciani, and J.-L. Florens, “CORDIS-ANIMA: A modeling and simulation system for sound and image synthesis—The general formalism,” Computer Music Journal, vol. 17, no. 1, pp. 19–29, Spring 1993.
[4] B. Verplank, “Haptic music exercises,” in Proc. of the Int. Conf. on New Interfaces for Musical Expression, Vancouver, BC, Canada, 2005, pp. 256–257.
[5] B. Gillespie and A. Okamura, “Haptic interaction for hands-on learning in system dynamics and controls,” accepted for publication in Con-

3URFHHGLQJV RI WKH WK 6RXQG DQG 0XVLF &RPSXWLQJ &RQIHUHQFH &RSHQKDJHQ 'HQPDUN -XO\

trol Systems Magazine, Last checked: | March
30, 2012: | http://www-personal.umich.edu/˜brentg/
Publications/Journal/2005e.htm.
[6] B. Verplank, M. Gurevich, and M. Mathews, “The Plank: designing a simple haptic controller,” in Proceedings of the 2002 conference on New Interfaces for Musical Expression, Dublin, Ireland, May 24-26 2002.
[7] E. Berdahl, A. Kontogeorgakopoulos, and D. Overholt, “HSP v2: Haptic signal processing with extensions for physical modeling,” in Proceedings of the Haptic Audio Interaction Design Conference, Copenhagen, Denmark, September 16-17 2010, pp. 61–62.
[8] E. Berdahl, G. Niemeyer, and J. Smith, “HSP: A simple and effective open-source platform for implementing haptic musical instruments,” in Proceedings of the Ninth International Conference on New Interfaces for Musical Expression, Pittsburgh, PA, June 4-6 2009, pp. 262–263.
[9] E. Berdahl, H.-C. Steiner, and C. Oldham, “Practical hardware and algorithms for creating haptic musical instruments,” in Proceedings of the International Conference on New Interfaces for Musical Expression (NIME-2008), Genova, Italy, June 5-7 2008, pp. 61–66.
[10] J. Castet, D. Courousse, and J.-L. Florens, “A real-time ´ simulator for virtual reality conceived around haptic hard constrains,” in Proc. International Conference on Enactive Interfaces, Grenoble, France, November 19-22 2007.
[11] J. Rodriguez, A. Shahrokni, M. Schrittenloher, and
M. Fjeld, “One-dimensional force feedback slider: Digital platform,” in IEEE VR 2007 Workshop on Mixed Reality User Interfaces: Specification, Authoring, Adaptation, 2007, pp. 47–51.
[12] R. Gabriel, J. Sandsjo, A. Shahrokni, and M. Fjeld, “Bounceslider: Actuated sliders for music performance and composition,” in Proceedings of the Second International Conference on Tangible and Embedded Interaction, Bonn, Germany, Feb 18-20 2008, pp. 127– 130.
[13] T. Andersen, R. Huber, A. Kretz, and M. Fjeld, “Feel the beat: Direct manipulation of sound during playback,” in First IEEE International Workshop on Horizontal Interactive Human-Computer Systems, January 5-7 2006.
[14] B. Verplank and F. Georg, “Can haptics make new music? - fader and plank demos,” in Proceedings of the International Conference on New Interfaces for Musical Expression, Oslo, Norway, May 30-June 1 2011.
[15] C. Cadoz, L. Lisowski, and J.-L. Florens, “A modular feedback keyboard design,” Computer Music Journal, vol. 14, no. 2, pp. 47–51, 1990.
[16] C. Cadoz, A. Luciani, J.-L. Florens, and N. Castagne,´ “Artistic creation and computer interactive multisensory simulation force feedback gesture transducers,” in Proceedings of the 2003 Conference on New Interfaces for Musical Expression, Montreal, Canada, 2003, pp. 235–246.
[17] E. Berdahl and J. Smith III, “An introduction to the Synth-A-Modeler compiler: Modular and open-source sound synthesis using physical models,” in Proceedings of the Linux Audio Conference, Stanford, CA, USA, April 2012.
[18] Y. Orlarey, D. Fober, and S. Letz, FAUST: An Efficient Functional Approach to DSP Programming. France: Edition Delatour, 2009.
[19] K. Kuchenbecker, J. Park, and G. Niemeyer, “Characterizing the human wrist for improved haptic interaction,” in Proceedings of the International Mechanical Engineering Congress and Exposition, Washington, DC, USA, Nov. 2003.
[20] E. Berdahl, J.-L. Florens, and C. Cadoz, “Using physical models is necessary to guarantee stabile analog haptic feedback for any new user and haptic device,” in Proceedings of the 8th Sound and Music Computing Conference, Padua, Italy, July 6-9 2011.
[21] C. Carlson, E. Marschner, and H. McCurry, “The sound flinger: A haptic spatializer,” in Proc. New Interfaces for Musical Expression, Oslo, Norway, May 30-June 1 2011, pp. 138–139.
[22] S. Gupta and J. Sadler, “PROJECT SQUEEZE: A low-cost 1-DOF exoskeletal haptic pincher,” Stanford University, CS277 Term Project Report, March 11 2012.
[23] E. Berdahl, G. Niemeyer, and J. O. Smith, “Using haptic devices to interface directly with digital waveguidebased musical instruments,” in Proceedings of the Ninth International Conference on New Interfaces for Musical Expression, Pittsburgh, PA, June 4-6 2009, pp. 183–186.
[24] E. Berdahl, “FireFader: A single degree-of-freedom force-feedback device for multimodal interaction with physical models,” in 162nd Meeting of the Acoustical Society of America, San Diego, CA, October 31-November 4 2011.
[25] A. Freed, “Application of new fiber and malleable materials for agile development of augmented instruments and controllers,” in Proceedings of the 2008 Conference on New Interfaces for Musical Expression, Genova, Italy, 2008.
[26] A. Hollinger and M. Wanderley, “Evaluation of commercial force-sensing resistors,” in International Conference on New Interfaces for Musical Expression, Paris, France, 2006.

3URFHHGLQJV RI WKH WK 6RXQG DQG 0XVLF &RPSXWLQJ &RQIHUHQFH &RSHQKDJHQ 'HQPDUN -XO\

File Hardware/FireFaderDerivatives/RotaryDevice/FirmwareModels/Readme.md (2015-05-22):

Simple models can be implemented directly in firmware for a higher quality result. However, it's more challenging to program such models. Here is an example designed for the rotary device when using a rotary encoder with 1000 counts/revolution.

I suggest uncommenting one line for unsignedForceA under 

// -------- BEGIN USER CODE TO CONTROL KNOB ---------  

and one line for unsignedForceB under 

// -------- END USER CODE TO CONTROL KNOB AND FADER ---------

to try out some examples. It should also be possible to superimpose the control laws specified by these lines of code.

It's necessary to use integers only to avoid slowing the control loop down too much. (Even a single floating point multiply can take 0.5ms!) I use mostly 8-bit and 16-bit integers, while occasionally using a few 32-bit integers when necessary.

With models like these, it's very hard to get high quality audio by programming, but as you will be able to see, the haptic quality can still be intriguing, and it is "more stable", allowing higher stiffnesses and damping parameters to be rendered.

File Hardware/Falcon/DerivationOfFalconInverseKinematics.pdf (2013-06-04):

1 | Theoretical Kinematics
1.1 | Plücker Coordinates

Julius Plücker (June 16, 1801 May 22, 1868) introduced the method of referencing lines as a set of coordinates, called Plücker coordinates [1], which maps a line in projective three-dimensional space to a point in projective ve-dimensional space (k-dimensional subspaces of n-dimensional space). This creates a new geometry where lines in three-dimensional space are the points of the new geometry[2].

To dene Plücker coordinates, we rst dene the meet and join operations of two linear subspaces. The meet of two subspaces is dened to be their maximum common intersection and the join of two subspaces is dened to be the minimum space enclosing both subspaces. For example, in general position, a line meets a plane at a point and a line joins a point into a plane.

1.1.1 Notation

Homogeneous coordinates make calculations possible in projective space. The notation used will be:

(V : 0) − A homogeneous vector, with V = (Vx, Vy, Vz).

(P : w) − A homogeneous point, with P =

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
[N : n] − A plane satisng N · P + n = NxPx + NyPy + NzPz + nw = 0 for any point P on the plane with N = (Nx, Ny, Nz) being the normal to the plane, n the moment of normal. {U : V } − A Plücker coordinate for a line, with U, V three-element vectors.
U · V − The dot product of vectors U and V.
U × V − The cross product of vectors U and V.

1.1.2 Derivation

Let us consider projective three-dimensional space with homogeneous coordinates. We will present a derivation for line coordinates based on [2] and [3] . First the standard determinant denition of Plücker coordinates, then a similar mapping based on geometry.

Let L be a line and let P and Q be two distinct points on L and let [E : e] and [F : f] be two distinct planes that contain L. Thus L is the join of P and Q and the meet of E and F. Assume the homogeneous coordinates for points P and Q are (p0 : p1 : p2 : p3) and (q0 : q1 : q2 : q3) respectively (i.e. P =

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
, Q =
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
). Since points P and Q both lie on planes [E : e] and [F : f], we have following equations:
E · P + e = 0, | E · Q + e = 0 and F · P + f = 0, | F · Q + f = 0

Let λij denote piqj − pj qi , using either plane we can equate elements and eliminate to get:

| 0Ex+λ10Ey+λ20Ez+λ30e =0 λ01Ex+ 0Ey+λ21Ez+λ31e =0 λ02Ex+λ12Ey+ 0Ez+λ32e =0 λ03Ex+λ13Ey+λ23Ez+ 0e =0

From the denition of λij , we know that λij = −λij and λii = 0. Therefore, only six dierent values describe the line L through P and Q. The Plücker coordinates from dierent pairs of points on a line only dier by a non-zero constant factor, being homogeneous coordinates of projective ve-dimensional space. If we choose {λ01 : λ02 : λ03 : λ32 : λ13 : λ21} as the coordinates the system of homogeneous (linear) equations, having a non-trivial solution, gives the following constraint:

λ01λ32 + λ02λ13 + λ03λ21 = 0

A similar mapping of a line L in projective three-dimensional space to a point in projective ve-dimensional space can be achieved if we dene the displacement vector from point P to point Q on the line (U = Q − P) as the rst three of Plücker coordinates and the cross product of the position vectors as the other three (V = Q × P). We now have

L = {U : V } = {Q − P : Q × P}

with U.V = 0 providing an equivalent constraint to that of the linear equations.

1.1.3 Relevant Plücker Coordinate Relationships

Here are a list of Plücker coordinate relations[3] relevant to the analysis presented below:

L= {Q − P : Q × P} , for A and B distinct points on L, and line is directed P → Q
L= {U : U × P} | , for U the direction of L and P a point on L
L= {pQ − qP : Q × P}, for (P : p) and (Q : p) distinct homogeneous points on L
L= {S × T : tS − sT} , for (S : s) and (T : t) distinct planes containing L
1.2 | Inverse Kinematics of the Novint Falcon Controller
1.2.1 | Geometric Analysis

Figure 1 shows an overview of the geometry with two triangular platforms. The nine key points,
Ai,, Bi | , Ci ,are visible. The centre of the smaller EE (end eector) is located at position P displaced
by (Px, Py, Pz) from the origin O at the centre of F F (xed frame). Note the design constraints. c is the side length of EE, a the side of FF, rc the distance CiBi and ra the distance AiBi

. A further
constraint is imposed by the circular trajectory of Bi at radius ra from the centre Ai (the dotted lines). A sphere, radius rc, centred on Ci gives the locus of Bi at radius ra from centre Ai

. The plane of
this arc cuts the sphere in a small circle in the same plane. The intersection of the arcs and circles yield Bi
| , with the solution external to FF and EE being valid. The desired actuated R-joint angles are
measured from an edge or line view of FF to AiBi as θi
| . The leg subscript i is omitted in all following
equations. It is obvious that a joint angle θ must be computed separately for each leg.

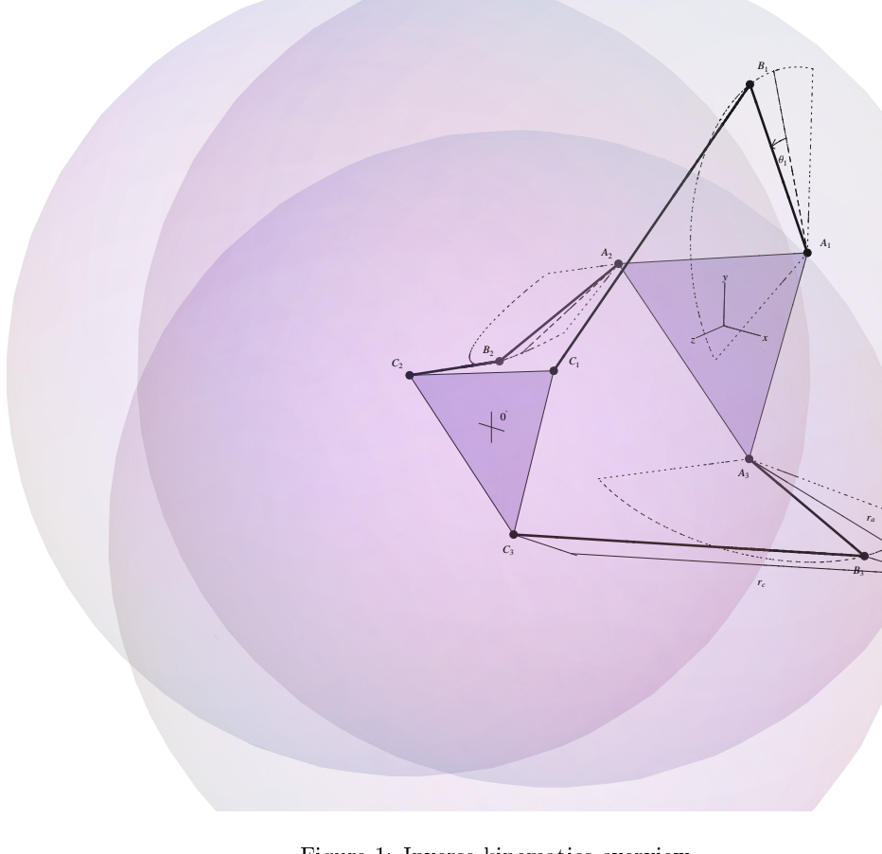
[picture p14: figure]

Figure 1: Inverse kinematics overview

1.2.2 Inverse Kinematic Computation

In this discussion, a line L will be intersected not with the sphere described above, centred on ankle C, but with the algebraically simpler one on A = (Ax, Ay, Az). The homogeneous coordinates of a point (B : w) on it are given by

(Axw − Bx)

2 + (Ayw − By)

2 + (Azw − Bz)

2 − r

2
aw
2 = 0 | (1)

where Az = 0 in the frame chosen. We dene L as the line through the two possible solutions of B. It is obtained by interecting the plane of a thigh circle on A with the plane of a circle produced by the interection of the sphere given by Eq. 1 and the one of radius rc centred on C. The homogeneous coordinates [T : t] of the three vertical thigh planes are:

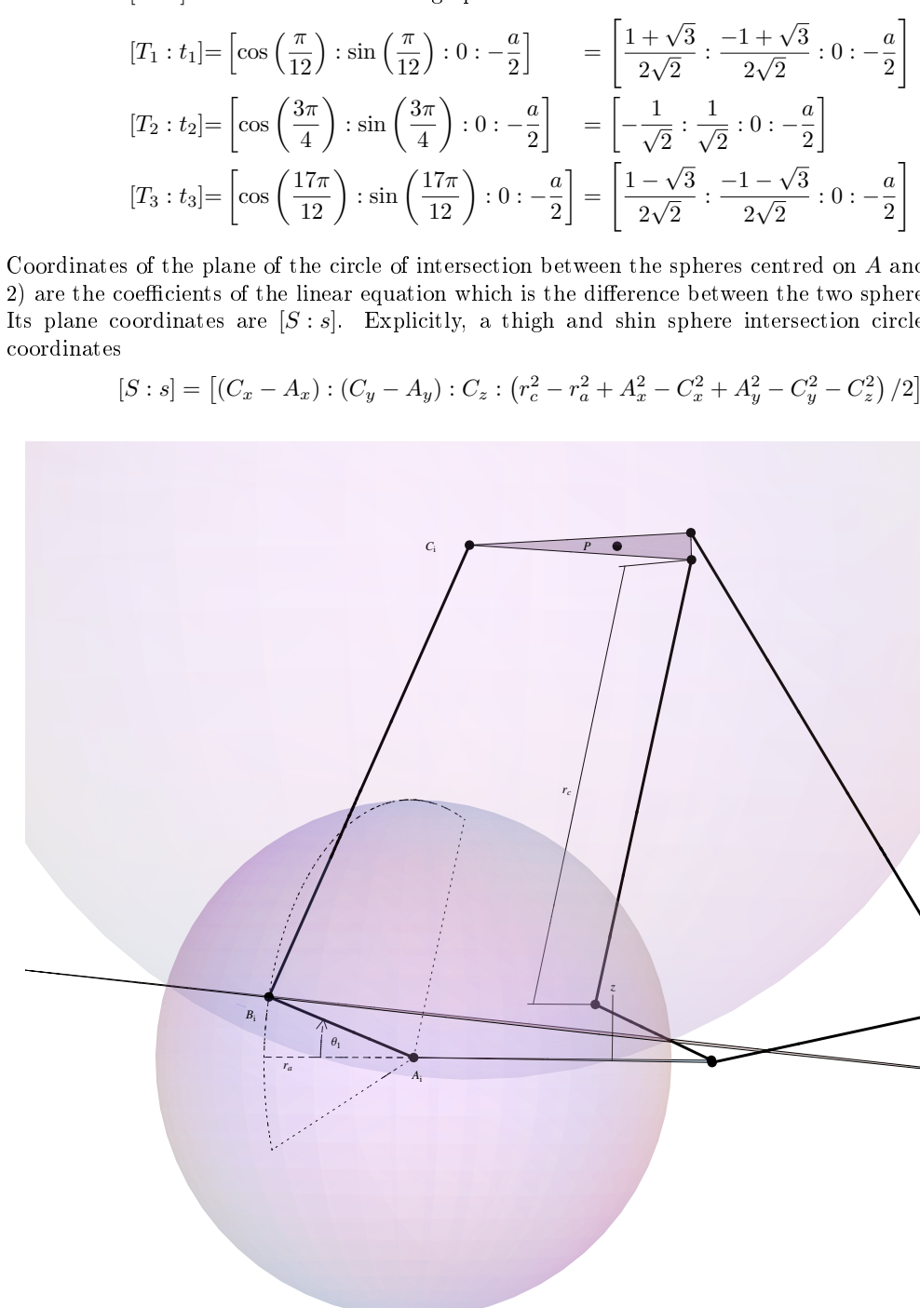
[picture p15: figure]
cos  π; : sin  π; cos ; : sin ; coordinates

Coordinates of the plane of the circle of intersection between the spheres centred on A and C (Figure
2) are the coecients of the linear equation which is the dierence between the two sphere equations. Its plane coordinates are [S : s]. Explicitly, a thigh and shin sphere intersection circle plane has

Figure 2: Intersection of the Ci and Ai spheres

The next step is to calculate the Plücker coordinates of the line that is the meet of these two planes:

L = {S × T : tS − sT} = {U : V }

Using the relationship of points on a plane for any point B on the line, we have T · B + t = 0 and S · B + s = 0. We can combine these equalities to create a set of linear equations:

0Bx+(SxTy − SyTx) By+(SxTz − SzTx) Bz+(Sxt − sTx) w =0
(SyTx − SxTy) Bx+ | 0By+(SyTz − SzTy) Bz+(Syt − sTy) w =0 | (2)
(SxTy − SyTx) Bx+(SxTy − SyTx) By+ | 0Bz+(Sxt − sTx) w =0
(sTx − Sxt) Bx+ | (sTy − Syt) By+ | (sTz − Szt) Bz+ | 0w =0

The coecients are the Plücker coordinates of the line L = {U : V } = {Ux : Uy : Uz : Vx : Vy : Vz}. The rst two lines of Eq. 2 can be rearranged to give

Bx =

Ux
Uz

Bz +

Vy
Uz

w

By =

Uy
Uz

Bz −

Vx
Uz

w

and substtituted into Eq. 1 to produce a quadratic in Bz, the z components for the intersections of the line L and the sphere of ra centred on A:

0 = -U

2
x + U

2
y + U

2
z
B

2
z − 2w [(AxUz − Vy)Ux + (AyUz + Vx)Uy] Bz+

w

2

h
(AxUz − Vy)

2 + (AyUz + Vx)

2 + AzU
2
z − r

2
aU

2
z

i
(3)

This is all that is required to nd θ = sin⁻¹ (Bz/ra). Each solution can be tested to obtain the correct angle, with angle in the range θ

7π
18 ,

11π
18

requiring special attention to determine if θ = sin⁻¹ (Bz/ra)
or θ = π − sin⁻¹
(Bz/ra).

One method is to use each value of Bz and the relations above to calculate the possible knee locations(Bx, By, Bz); the vectors A → B and A → C, along with the normal of the thigh plane [T : t] provide the following
test for validity:
T · ((B − A) × (C − A)) > 0 , for valid Bz | (4)

References

[1] J. Plücker, Neue Geometrie des Raumes. Leipzig, 1868.
[2] D. M. Mount and F. T. Pu, Binary Space Parititions in Plücker Space, Algorithm Engineering and Experimentation, (ALENEX'99), 1999.
[3] K. Shoemake, Plücker Coordinate Tutorial, Ray Tracing News, 1998.

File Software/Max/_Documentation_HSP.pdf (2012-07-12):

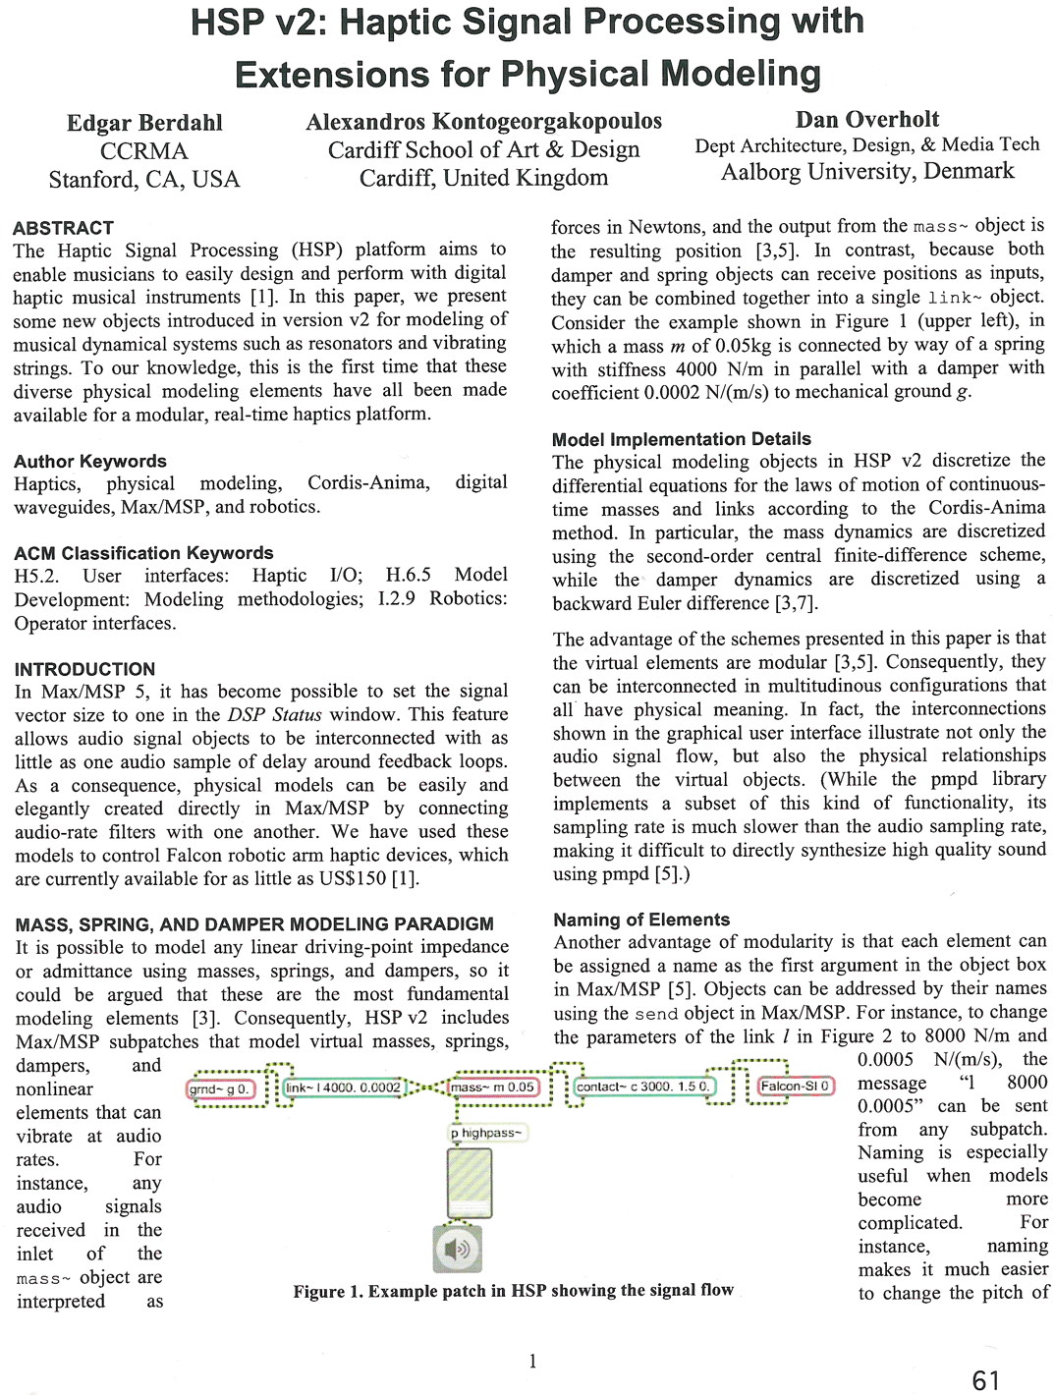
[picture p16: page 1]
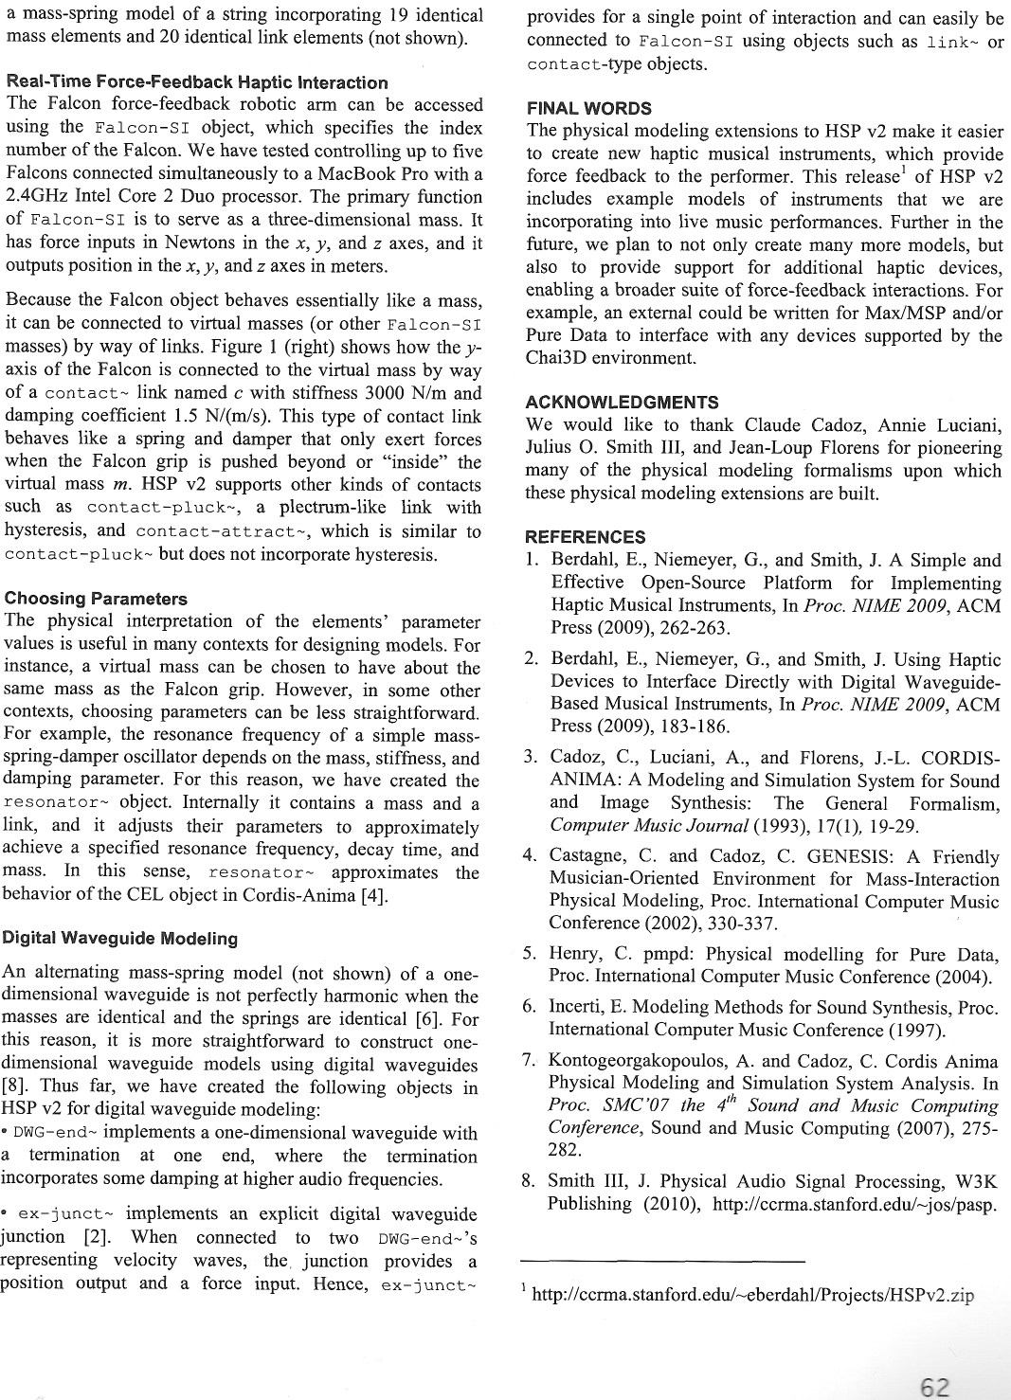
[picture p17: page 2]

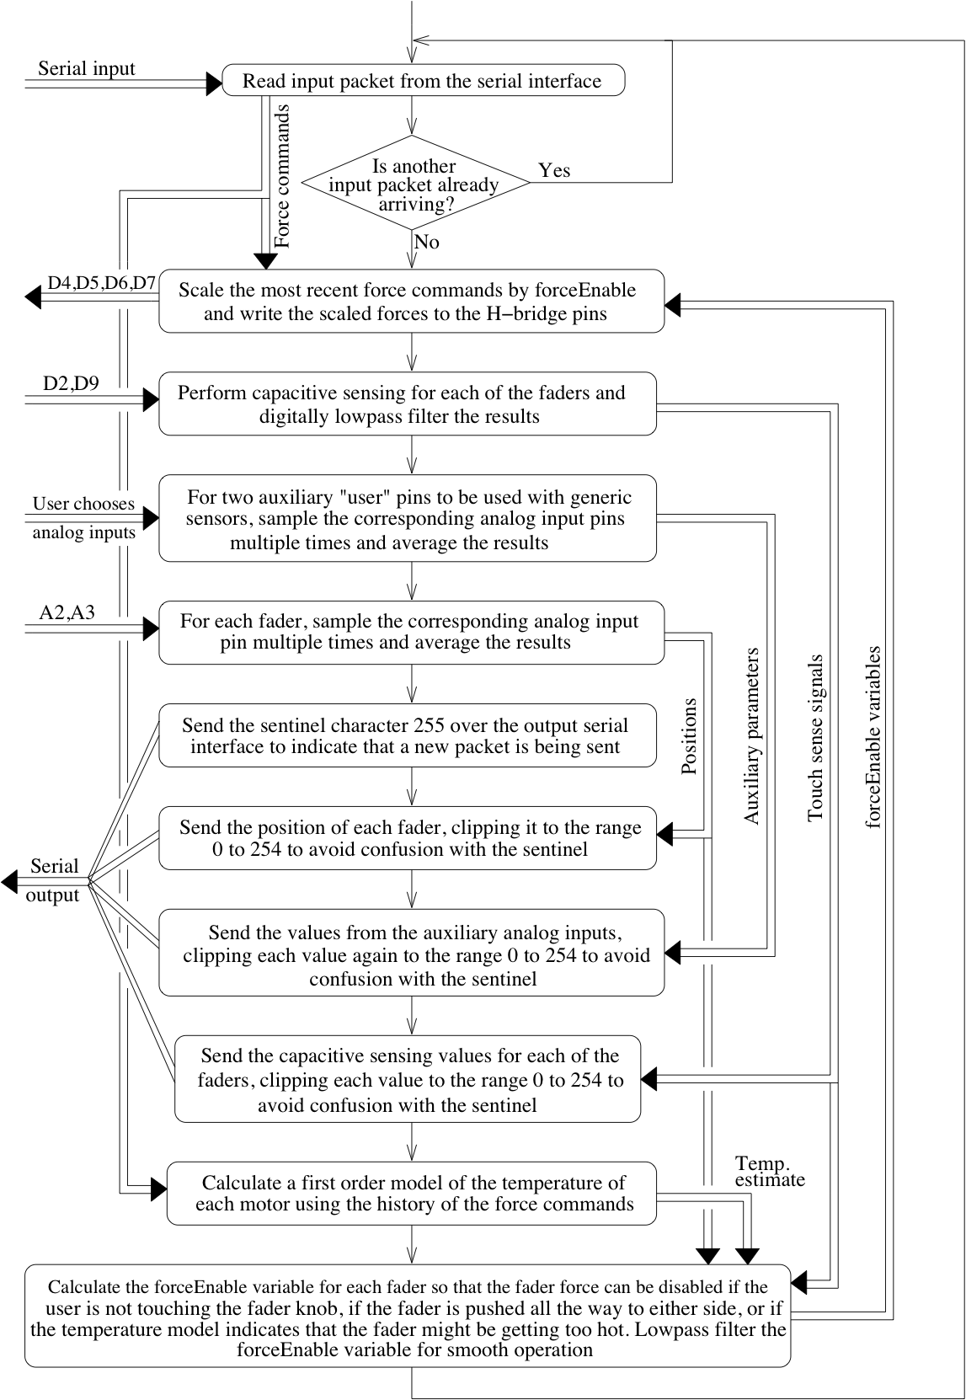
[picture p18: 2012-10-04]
Hardware/FireFader/Firmware/haptics_firmware/Firmware.png

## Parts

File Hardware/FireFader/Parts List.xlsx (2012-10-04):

Parts for FireFader |  |  |  |  | Approx price
By Edgar Berdahl, July 2012 and Sept 2012
Enclosure | Strapubox | Strapubox 2003 SW | 160mm x 83mm x 52mm | http://www.segor.de
Microcontroller | Gravitech | Arduino Nano 3.0 |  | http://www.gravitech.us/arna30wiatp.html
Motor controller | Gravitech | 2 MOTOR add-on for Arduino Nano |  | http://www.gravitech.us/2mwfecoadfor.html
2 x Motorized fader | ALPS | RSA0N11M9-LIN10K at reichelt.de (has extra pin for capacitive sensing) and 688-RSA0N11M9A05 at mouser.com (seems to be missing extra pin for capacitive sensing)
2 x Fader knobs |  | Either metalized knobs from Penny+Giles (expensive) |  | On Ebay "Familygate" sells metalized fader knobs
4 x Machine screws for enclosure
2 x 1 Mohm resistor
Approx. 12V power supply, at least 2A
2 x 12V lamps/LED lamp-replacements for indicating motor force are also nice (depending on lighting might need to also buy diode bridges)
USB mini cable

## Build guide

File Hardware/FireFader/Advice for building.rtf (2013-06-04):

Construction process:

- carefully push on the knobs with sliders at one end (also solder the brown ground wire to the case of the sliders to improve the capacitive sensing performance)

- load firmware onto the arduino

- test sensing capability using only usb power

- solder/connect remaining high current wires

- test the springs model in Max/MSP, while holding the power cord ready to remove it in case of force polarity error

Note: Be careful with heat gun -- it is possible to melt a part of the fader.

Note: If building by soldering wires directly to the motor controller board, use heat shrink when soldering to pins A2 and D2.

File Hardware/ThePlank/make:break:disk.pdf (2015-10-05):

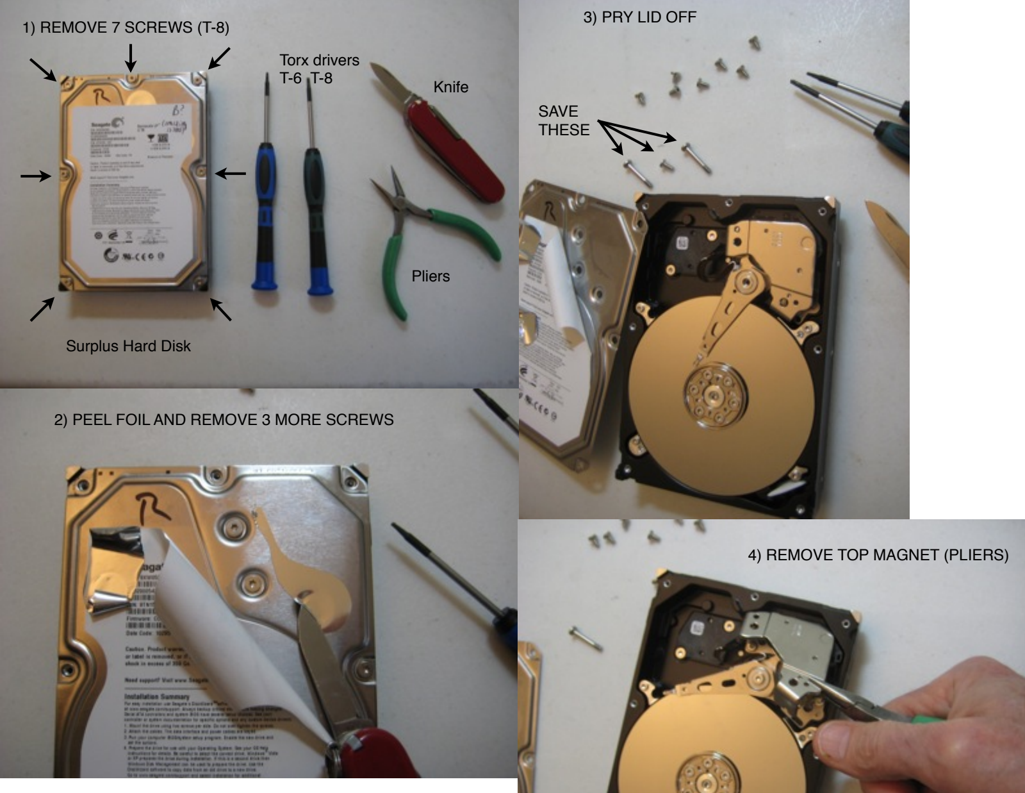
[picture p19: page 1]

Surplus Hard Disk

Torx drivers
T-6 T-8 | Knife

Pliers

1) REMOVE 7 SCREWS (T-8)
2) PEEL FOIL AND REMOVE 3 MORE SCREWS
3) PRY LID OFF

SAVE
THESE
4) REMOVE TOP MAGNET (PLIERS)

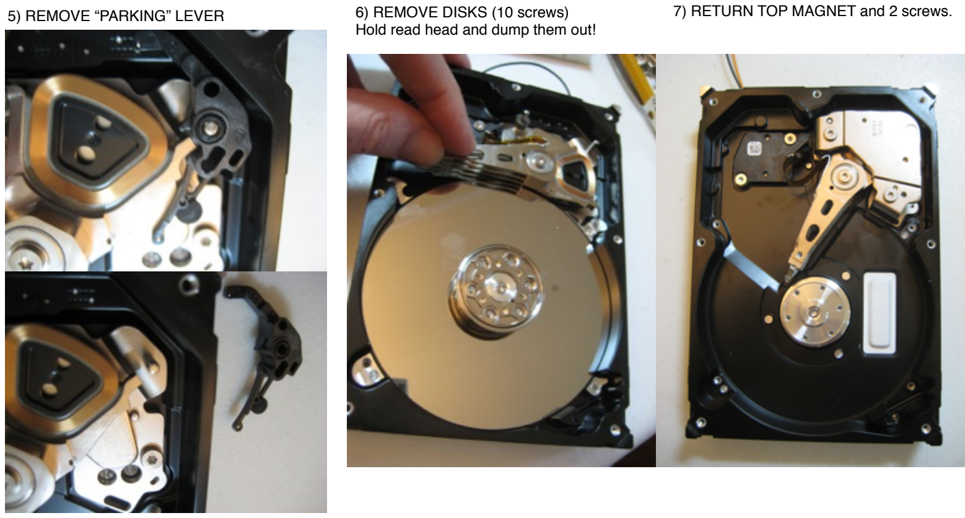
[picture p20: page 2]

6) REMOVE DISKS (10 screws)
Hold read head and dump them out! 5) REMOVE “PARKING” LEVER | 7) RETURN TOP MAGNET and 2 screws.

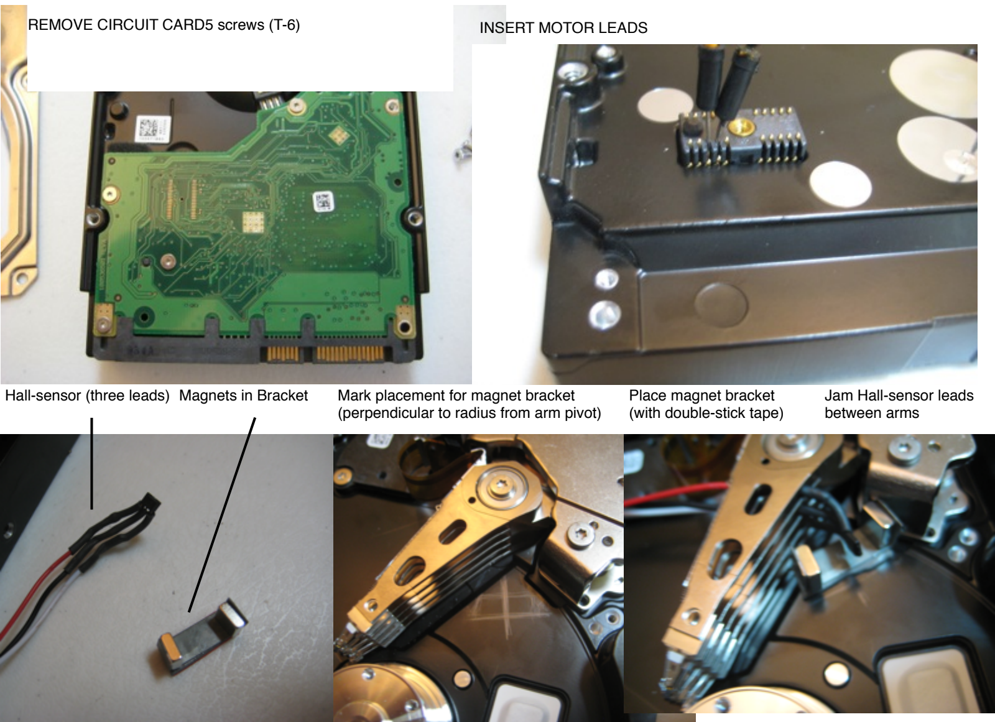
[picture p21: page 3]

Hall-sensor (three leads) Magnets in Bracket Mark placement for magnet bracket (perpendicular to radius from arm pivot)

Place magnet bracket
(with double-stick tape)

Jam Hall-sensor leads
between arms
REMOVE CIRCUIT CARD5 screws (T-6) | INSERT MOTOR LEADS

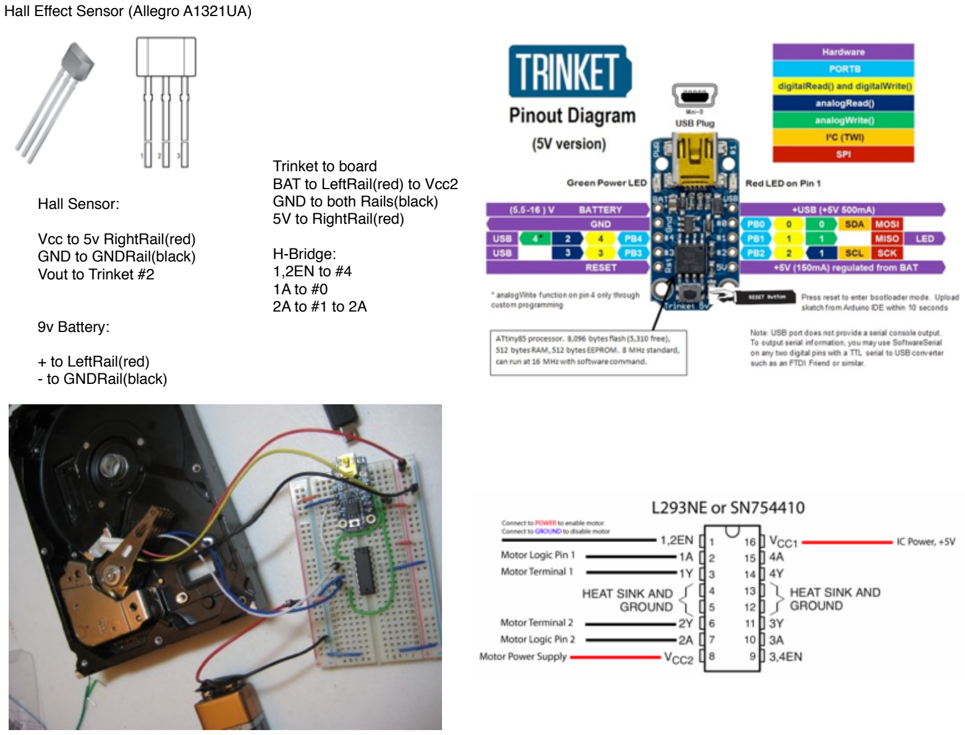
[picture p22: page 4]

Hall Effect Sensor (Allegro A1321UA)

Trinket to board
BAT to LeftRail(red) to Vcc2 GND to both Rails(black)
5V to RightRail(red)

H-Bridge:
1,2EN to #4
1A to #0
2A to #1 to 2A

Hall Sensor:

Vcc to 5v RightRail(red)
GND to GNDRail(black)
Vout to Trinket #2

9v Battery:

+ to LeftRail(red)
- to GNDRail(black)

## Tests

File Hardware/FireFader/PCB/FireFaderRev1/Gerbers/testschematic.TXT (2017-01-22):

%
M48
M72
T01C0.0236
T02C0.0315
T03C0.0320
T04C0.0354
T05C0.0440
T06C0.0472
T07C0.0700
T08C0.0709
T09C0.0728
T10C0.0787
T11C0.1102
T12C0.1260
T13C0.1300
%
T01
X9000Y13600
T02
X11500Y23100
X12500Y23100
X13500Y23100
X14500Y23100
X15500Y23100
X16500Y23100
X17500Y23100
X18500Y23100
X19500Y23100
X20500Y23100
X21500Y23100
X22500Y23100
X23500Y23100
X24500Y23100
X25500Y23100
X25500Y29100
X24500Y29100
X23500Y29100
X22500Y29100
X21500Y29100
X20500Y29100
X19500Y29100
X18500Y29100
X17500Y29100
X16500Y29100
X15500Y29100
X14500Y29100
X13500Y29100
X12500Y29100
X11500Y29100
T03
X13500Y20100
X13500Y19100
X39500Y18600
X39500Y19600
X40000Y2100
X40000Y1100
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

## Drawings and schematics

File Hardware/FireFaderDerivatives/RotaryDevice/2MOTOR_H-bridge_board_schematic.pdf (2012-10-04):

# ARDUINO NANO SOCKET

OUTA | OUTB

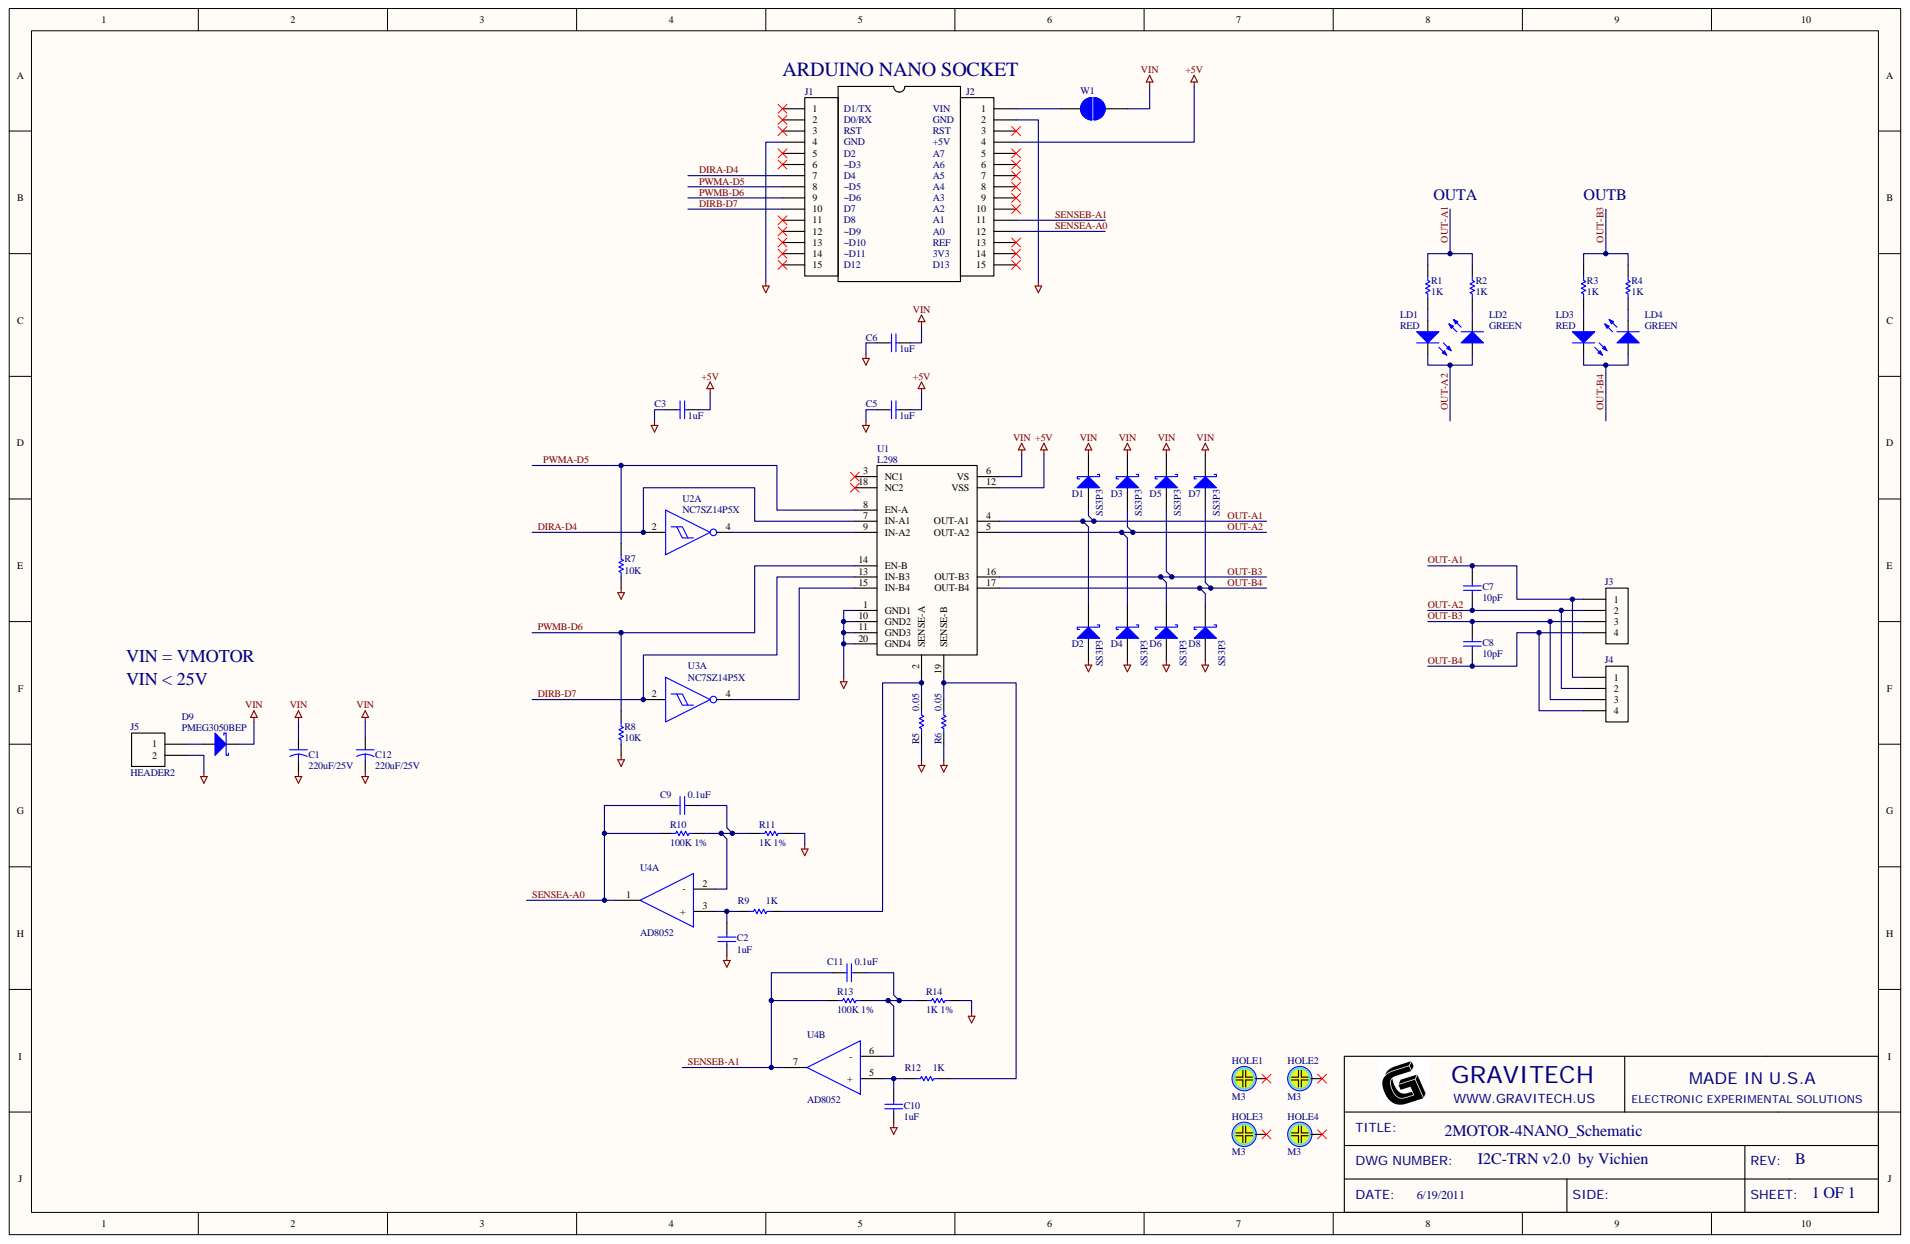
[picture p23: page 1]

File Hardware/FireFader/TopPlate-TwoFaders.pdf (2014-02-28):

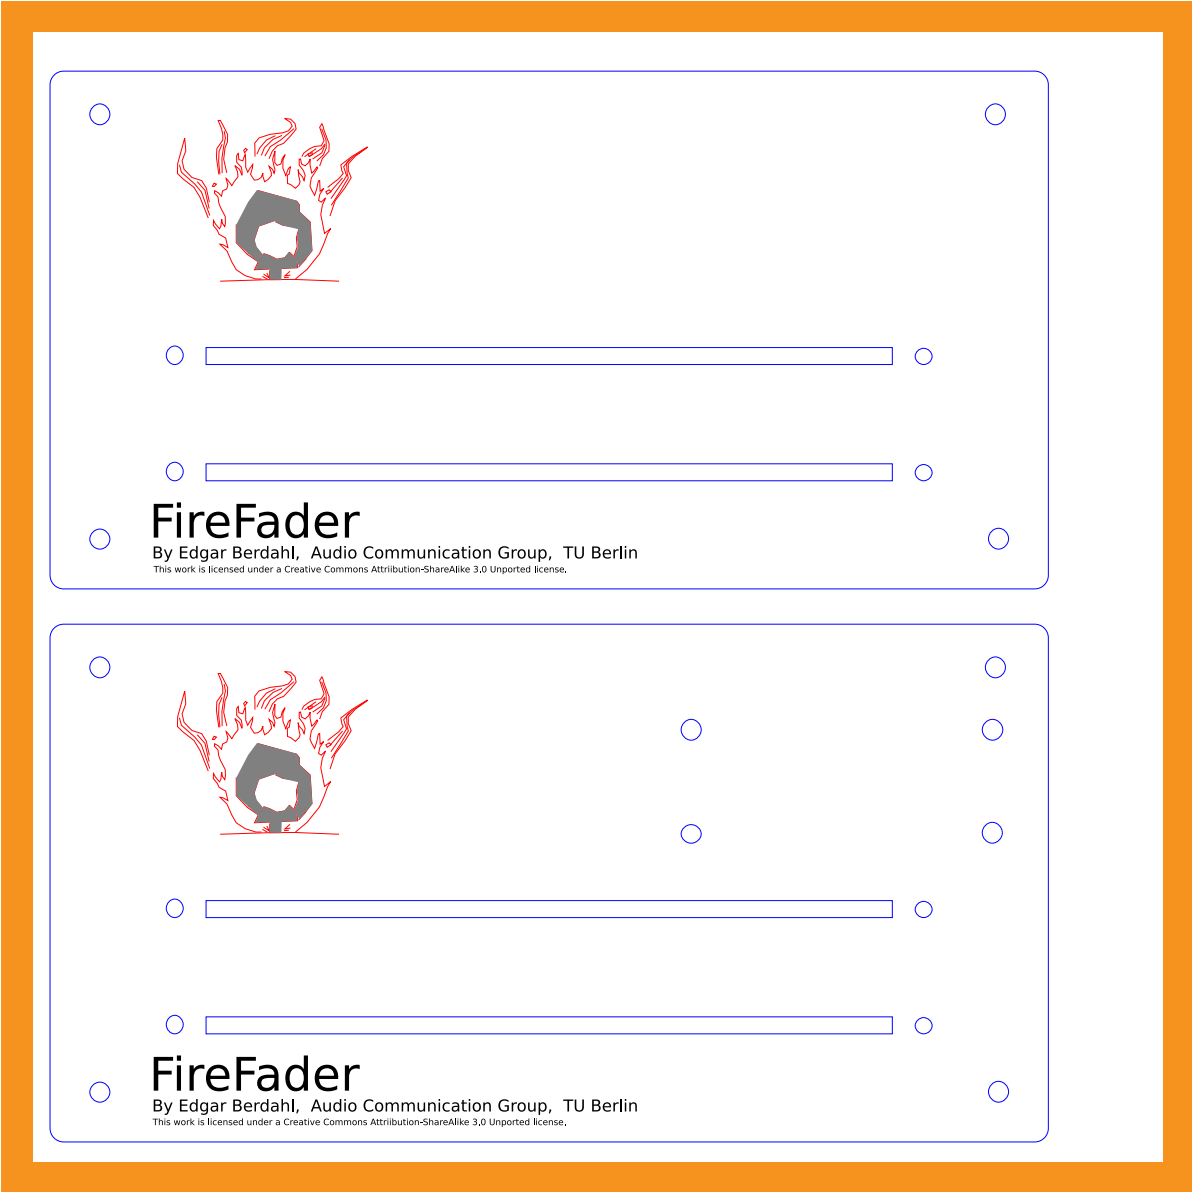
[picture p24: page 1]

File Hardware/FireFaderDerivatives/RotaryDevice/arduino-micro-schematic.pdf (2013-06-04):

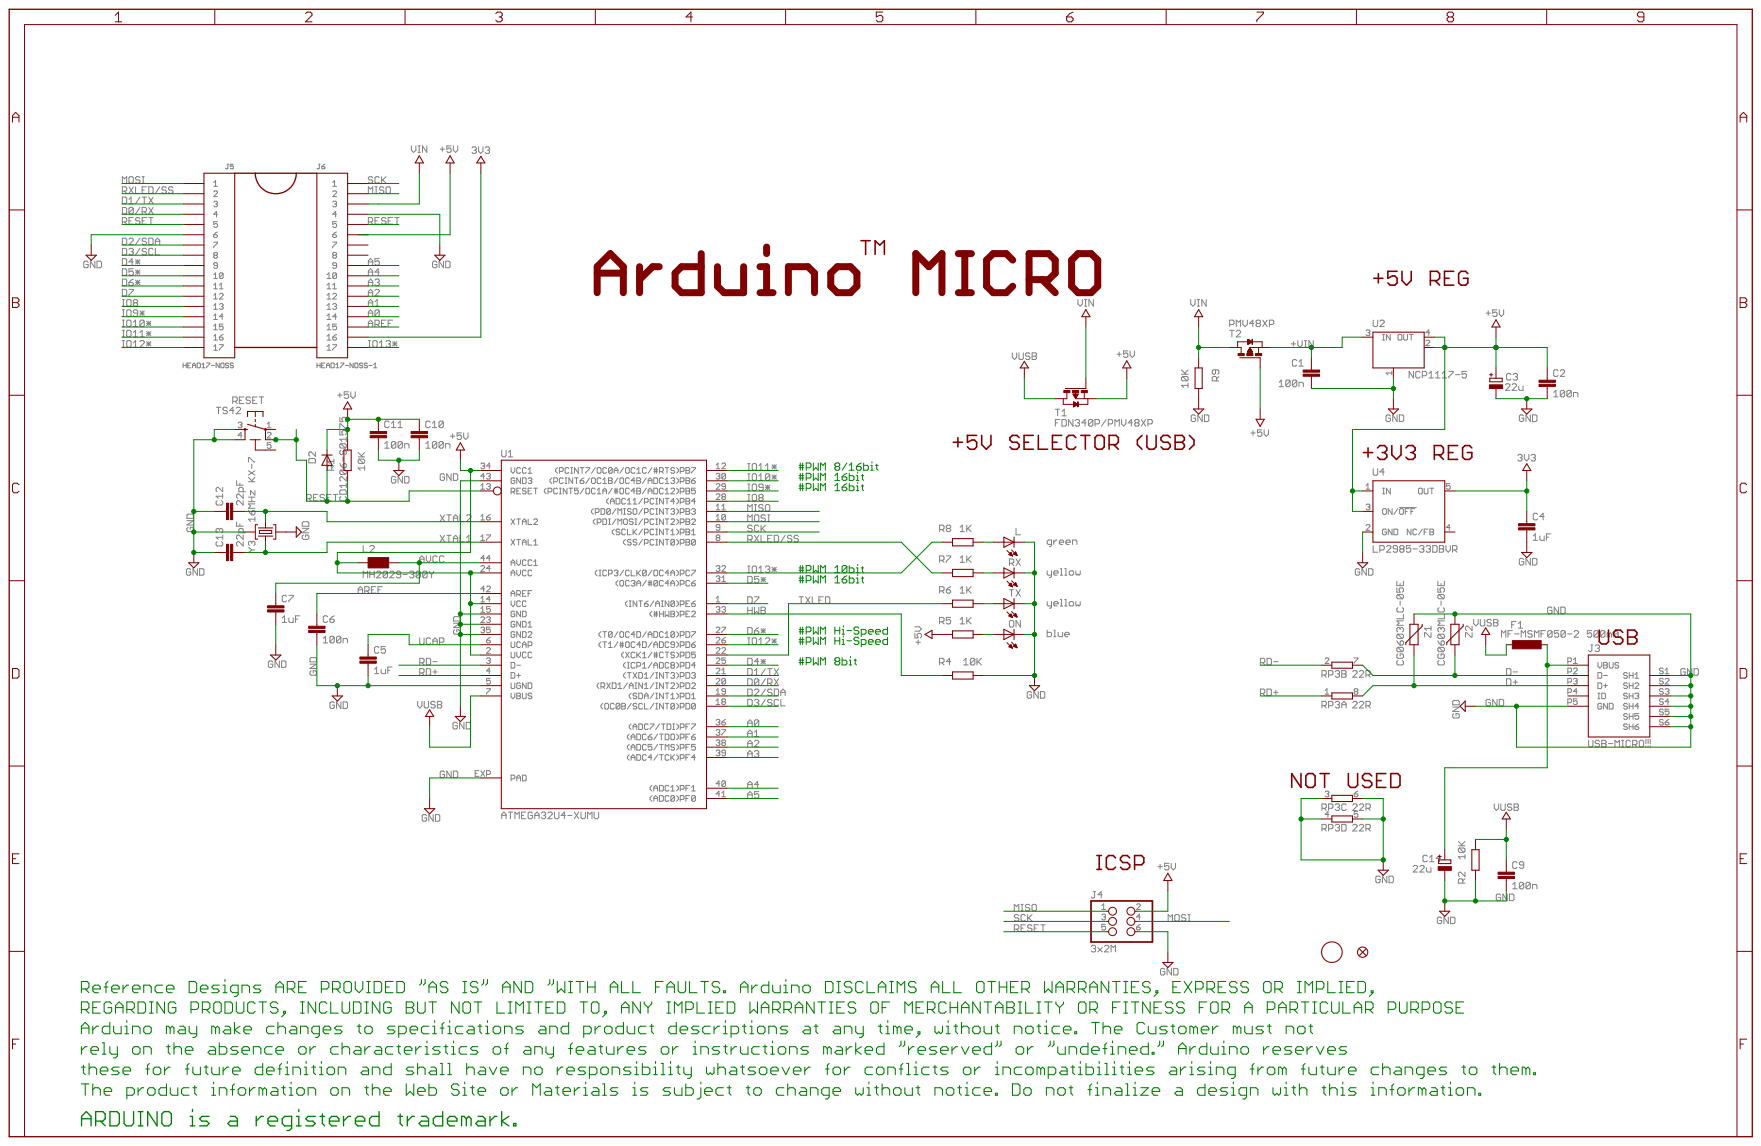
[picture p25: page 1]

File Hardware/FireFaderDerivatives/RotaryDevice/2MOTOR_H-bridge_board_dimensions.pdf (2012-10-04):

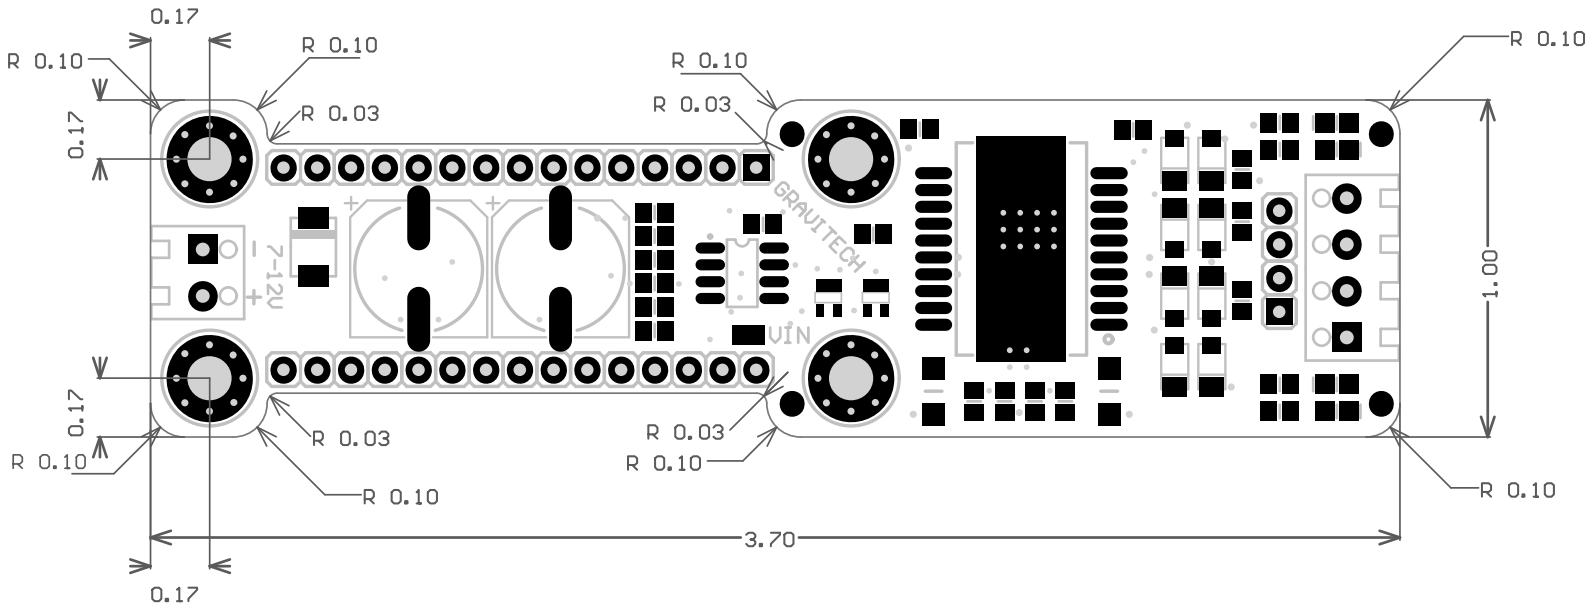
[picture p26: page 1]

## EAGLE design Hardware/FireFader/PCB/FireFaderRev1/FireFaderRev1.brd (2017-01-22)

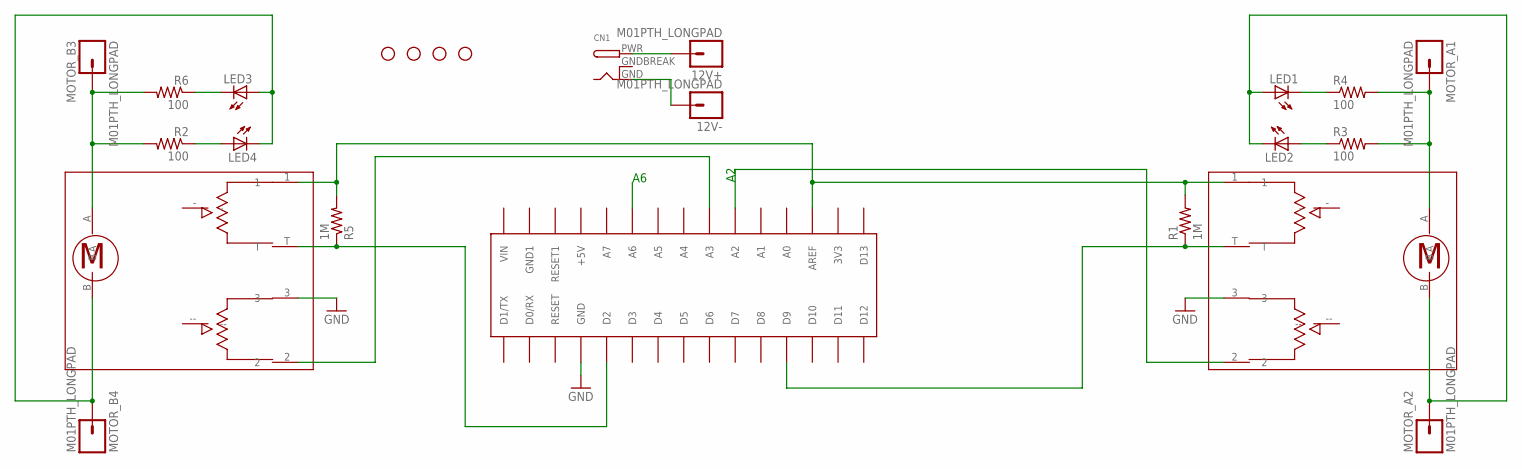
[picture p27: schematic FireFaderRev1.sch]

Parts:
12V+, 12V-: M01PTH_LONGPAD; 1X01_LONGPAD
CN1: DCBARRELPTH; DCJACK_2MM_PTH
LED1, LED2, LED3, LED4: LED5MM
MOTOR_A1, MOTOR_A2: M01PTH_LONGPAD; 1X01_LONGPAD
MOTOR_B3, MOTOR_B4: M01PTH_LONGPAD; 1X01_LONGPAD
R1, R5: 1M; AXIAL-0.4
R2, R3, R4, R6: 100; AXIAL-0.6
STANDOFF1, STANDOFF2, STANDOFF3, STANDOFF4: STAND-OFF
U$1: ARDUINONANO; PDIP-32
U$2, U$3: ALPS-RSA0N11M9A07; MF-MOTORFADER-ALPS

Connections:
A1: U$1.A3, U$3.2
A2: U$1.A2, U$2.2
A6: U$1.A6
AREF: R1.P$2 (2), R5.P$2 (2), U$1.AREF, U$2.1, U$3.1
GND: U$1.GND, U$2.3, U$3.3
GNDBREAK: CN1.GNDBREAK
MA1: MOTOR_A1.1, R3.P$2 (2), R4.P$2 (2), U$2.A
MA2: LED1.A, LED2.K (C), MOTOR_A2.1, U$2.B
MB3: MOTOR_B3.1, R2.P$2 (2), R6.P$2 (2), U$3.A
MB4: LED3.A, LED4.K (C), MOTOR_B4.1, U$3.B
unnamed: LED2.A, R3.P$1 (1)
unnamed: LED1.K (C), R4.P$1 (1)
unnamed: R1.P$1 (1), U$1.D9, U$2.T
unnamed: 12V-.1, CN1.GND
unnamed: 12V+.1, CN1.PWR
unnamed: R5.P$1 (1), U$1.D2, U$3.T
unnamed: LED4.A, R2.P$1 (1)
unnamed: LED3.K (C), R6.P$1 (1)

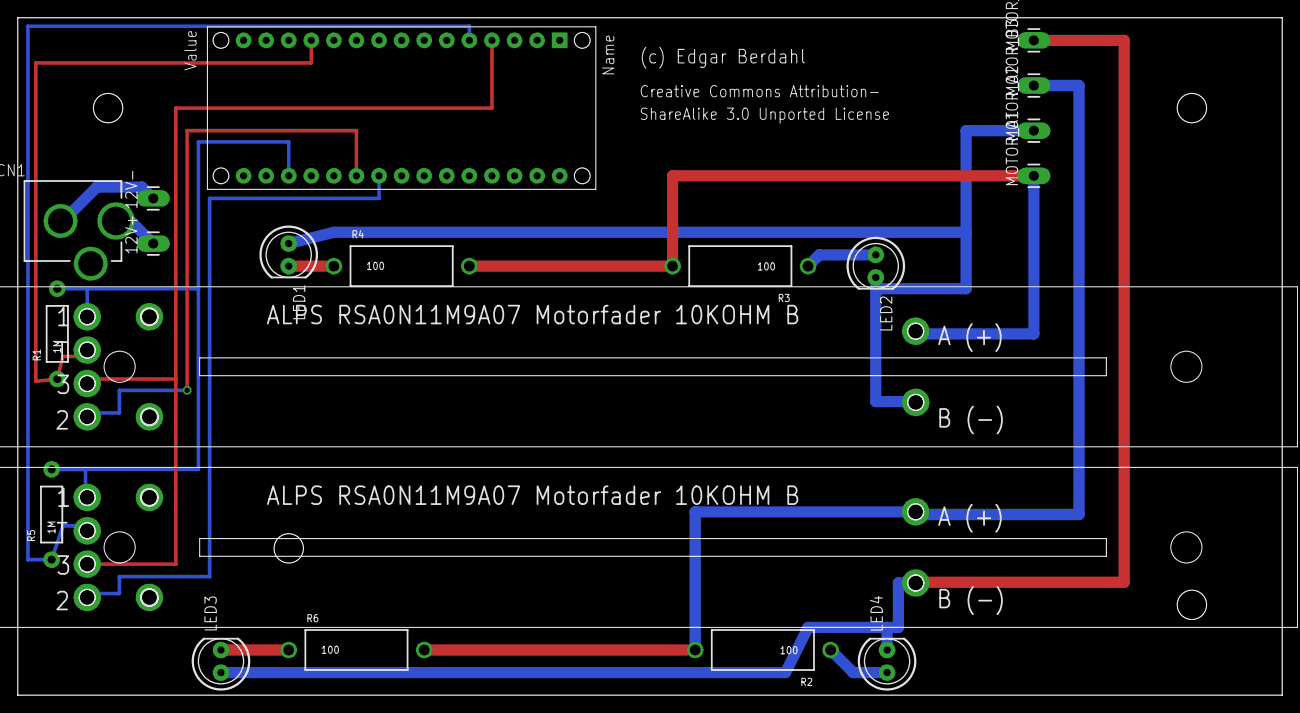
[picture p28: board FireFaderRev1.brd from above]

Board: 2 copper layers, 142.2 x 76.2 mm, 24 parts (0 on the bottom side), 16 nets.

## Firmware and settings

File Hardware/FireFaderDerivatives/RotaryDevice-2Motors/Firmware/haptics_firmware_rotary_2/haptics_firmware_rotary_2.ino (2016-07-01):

// Haptics firmware for the FireFader
//
// 8-bit numbers are used to simplify the code here and in the host application on the laptop.
//
// Some noise in the ADC can affect the sensor measurements.  We can greatly reduce the noise by using 
// averaging techniques (i.e. by low-pass filtering the signals).
//
// To reduce the time to get through the main loop, the ADC speed is set to a 
// faster speed than usual.



// History
// -------
// Autumn 2010:  A version of this firmware was first written by Edgar Berdahl
//
// January 2012:  Modified for http://www.gravitech.us/2mwfecoadfor.html
//
// May 2012:  Cleaned up the source code and updated for two faders.
//
// March 2013:  Added support for Arduino Micro and verified significantly reduced latency.
//
// September 2014:  Modified so that motor A is actually a rotary moder with an optical encoder.



// Divide the torque for the rotational motor by 2^(BITSTOSHIFTTORQUE)
// The default value is 1 (e.g. for a typical 12V DC motor)
#define BITSTOSHIFTTORQUE 1

// Divide the angular measurement by 2^(BITSTOSHIFTANGLESENSING)
// The default value is 2 (e.g. for a rotary encoder with 1000 counts/revolution)
#define BITSTOSHIFTANGLESENSING 2




int encoder0PinA = 2;  // "yellow" phase for motor A
int encoder1PinA = 3;  // "yellow" phase for motor B
int motorAwhitephase = 11;  // "white" phase for motor A
int motorBwhitephase = 12;  // "white" phase for motor B
volatile int encoder0Pos;
volatile int encoder1Pos;
int valOld = LOW;
int valNew = LOW;



int dirPinA = 4;  // Direction control of Motor A 
int PWMpinA = 5;  // PWM speed control of Motor A
int dirPinB = 7;  // Direction control of Motor B
int PWMpinB = 6;  // PWM speed control of Motor B


// These pins relate to the motor controller board's capability to measure the current it is sending through each motor.
int currentPinA = 0;   // for Nano v2.3 and 3.0, this is pin 1   (or 6 on older version of the Arduino Nano with 4-layer board)
int currentPinB = 1;   // for Nano v2.3 and 3.0, this is pin 0   (or 7 on older version of the Arduino Nano with 4-layer board)


// The analog input pins 4, 5, 6, and 7 are still free and could be used for other sensors.
// However, by default the firmware senses the current pins.  If you actually wanted to use these current measurements though
// you would need to low-pass filter them.
int extraAnalogInA = currentPinA;
int extraAnalogInB = currentPinB;


// The following pin is for measuring the position of the fader.
int potPinA = 2;        // for Nano v2.3 and 3.0, this is pin 3
int potPinB = 3;        // for Nano v2.3 and 3.0, this is pin 2 (or 5 on old Nano)



int capSensePinA = 9;        // The capacitive sensing "input" is at pin D9.
int capSensePinB = 10;        // The capacitive sensing "input" is at pin D10.
long capSenseLPFA = 0;       // The capacitive sensing input is lowpass-filtered using this state variable.
long capSenseLPFB = 0;       // The capacitive sensing input is lowpass-filtered using this state variable.




int forceAEnableLPF = 0;
int forceBEnableLPF = 0;

long heatA = 0;
long heatB = 0;

// This function carries out the analog reads and averaging.
//
// It samples the analog input pinNum timesToRead times and then shifts the result
// down by bitsToShift number of bits, which is equivalent to dividing by 2^bitsToShift.
//
// Normally, the user will select timesToRead = 2^bitsToShift
inline int analogReadAveraging(int pinNum, int timesToRead, int bitsToShift){
    unsigned int val=0;
    int i;
  
    for (i=0; i<timesToRead; i++)
      val += analogRead(pinNum);
  
    val = val >> bitsToShift;  // This is equivalent to dividing val by 2^bitsToShift
  
    return (signed int)val;
}








// The setup() function runs only once, and it happens shortly after the Arduino is turned on.
void setup()
{
  // First open the serial connection via the USB
  Serial.begin(57600);    // The speed only seems to matter for Arduinos with FTDI chips (such as Arduino Nano but not Micro or Leonardo)

  // Setup encoder
  pinMode (encoder0PinA,INPUT); 
  pinMode (encoder1PinA,INPUT);
  pinMode (motorAwhitephase, INPUT);
  pinMode (motorBwhitephase, INPUT);
  attachInterrupt(digitalPinToInterrupt(encoder0PinA), CountA, CHANGE);
  attachInterrupt(digitalPinToInterrupt(encoder1PinA), CountB, CHANGE);
  encoder0Pos = 128 << BITSTOSHIFTANGLESENSING;  // Start counting at zero meters
  encoder1Pos = 128 << BITSTOSHIFTANGLESENSING;  // Start counting at zero meters
  
  // Setup capacitive sensing
  pinMode(capSensePinA, OUTPUT);
  digitalWrite(capSensePinA, 0);
  pinMode(capSensePinB, OUTPUT);
  digitalWrite(capSensePinB, 0);
  delay(10);
  capSenseLPFA = 0;   // Set the capacitive sensing state variables to 0
  capSenseLPFB = 0;   // Set the capacitive sensing state variables to 0

  // Set pin D8 to 5V to use as power supply for capacitive sensing of knob
  pinMode(8, OUTPUT);
  digitalWrite(8, 1);

  // On the Arduino Micro, the following makes the PWM frequency sufficiently high on pins 3 and 11:
#ifdef TCCR3B
  TCCR3B = TCCR3B & 0b11111000 | 0x01;
#endif
#ifdef TCCR4B
  TCCR4B = TCCR4B & 0b11110000 | 0x01;   // uses 4 lowest bits to set prescaler instead of 3 lowest bits
#endif   

  // On the Arduino Leonardo or Uno, the following makes the PWM frequency sufficiently high on pins 3 and 11:
#ifdef TCCR2B
  //TCCR2B = TCCR2B & 0b11111000 | 0x01;
#endif

  // On the Arduino nano, the following code sets the PWM frequency to 31250Hz on pins D5 and D6
 // TCCR0B = TCCR0B & 0b11111000 | 0x01;   // (see section 14.9.2 "TCCR0B – Timer/Counter Control Register B" in ATMega328 full-length data sheet)

  
  // Here we make the ADC run faster:
  // - defines for setting and clearing register bits
  #ifndef cbi
  #define cbi(sfr, bit) (_SFR_BYTE(sfr) &= ~_BV(bit))
  #endif
  #ifndef sbi
  #define sbi(sfr, bit) (_SFR_BYTE(sfr) |= _BV(bit))
  #endif
  // - set prescale to 16, to increase the "ADC sampling rate" from 9600Hz to 77kHz
  sbi(ADCSRA,ADPS2);
  cbi(ADCSRA,ADPS1);
  cbi(ADCSRA,ADPS0);


  // Finally we initialize our input and output pins
  pinMode (PWMpinA, OUTPUT);
  analogWrite(PWMpinA, 0);
  pinMode (dirPinA, OUTPUT);
  pinMode (potPinA, INPUT);
}











// This "interrupt routine" function gets called immediately when the "yellow" phase changes on motor A
void CountA()   
{ 
  volatile int n = digitalRead(encoder0PinA);  // Phase "yellow" just changed to this new value n --> the motor is turning
  volatile int m = digitalRead(motorAwhitephase);  // Phase "white" currently has this value
  
  if (m == HIGH) {
    if (n == LOW) {
      encoder0Pos++;
    } else if (n == HIGH) {
      encoder0Pos--;
    }
    
  } else if (m == LOW) {
     if (n == LOW) {
      encoder0Pos--;
    } else if (n == HIGH) {
      encoder0Pos++;
    }
  }
}





// This "interrupt routine" function gets called immediately when the "yellow" phase on motor B changes
void CountB()
{
  volatile int n = digitalRead(encoder1PinA);  // Phase "yellow" just changed to this new value n --> the motor is turning
  volatile int m = digitalRead(motorBwhitephase);  // Phase "white" currently has this value
  
  if (m == HIGH) {
    if (n == LOW) {
      encoder1Pos--;
    } else if (n == HIGH) {
      encoder1Pos++;
    }
    
  } else if (m == LOW) {
     if (n == LOW) {
      encoder1Pos++;
    } else if (n == HIGH) {
      encoder1Pos--;
    }
  }
}








// This helper function prevents misinterpreting sensor data
// as the sentinel character 255 when streaming over the serial
// connection to the laptop.
inline void SerialWriteNo255(int input){
  if (input > 254) {
    Serial.write((uint8_t)254);
  } else if (input < 0) {
    Serial.write((uint8_t)0);
  } else {
    Serial.write((uint8_t)input); 
  } 
}







// This helper function sets the output PWM pins
inline int setPWM(int PWMpin, int dirPin, int force, int forceEnable, int bitsToShift){
  
  
  if (force > 127)              // Convert unsigned char back to signed char
    force = force - 256;        // if necessary.
 
  // This maps to the range of the PWM
  force = force * 2;  // i.e. map input range from serial [-127 127] to [-254 254]
  
  // To implement (mechanical) impedance matching with motors with different motor constants
  force = (force >> bitsToShift);
  
  // For safety, we could optionally clip the force range here to half (this is good for beginning users)
    /*if (force > 127)
      force = 127;
    if (force < -128)
      force = -128;*/
      
  // Due to the lowpass filter design, forceEnable has a maximum of 129.  However, there can be some
  // noise in the forceEnable variable.  For now, the force is enabled unless forceEnable falls beneath
  // a certain threshold:
  if (forceEnable < 20)
    force=0;
  
  // Then we have to set the force direction pin and the force magnitude (PWM) pins accordingly
  if (force > 0) {
      analogWrite(PWMpin, force);
      digitalWrite(dirPin, LOW);
  } else {
      analogWrite(PWMpin, -force);
      digitalWrite(dirPin, HIGH);
  }
  
  return force;
}







// Perform capacitive sensing and lowpass filter the result with a one-pole lowpass filter
// This takes max. about 175 microseconds
inline long capSenseAndFilter(long capSenseLPF, int capSensePin){
  // The variables for the capacitive sensing are defined as "volatile" to prevent the
  // compiler from reordering those lines of code.
  volatile int capSense = 0;
  
  // First we multiply the capSenseLPF state variable by 0.875 (the computation looks weird because we have to do it using integers).
  capSenseLPF = capSenseLPF * 7;
  capSenseLPF = capSenseLPF >> 3;   // This is equivalent to dividing by 8
  
  // After setting the capacitive sensing pin low,
  pinMode(capSensePin, INPUT);
  
  // we wait in a loop until the capacitive sensing pin goes high
  // due to the 1Mohm resistor to 5V.
  capSense = 0;
  while(digitalRead(capSensePin) == 0) {
    if (capSense >= 15)     // Terminate early if taking too long to ensure that the program never stops running.
      break;                // 255 instead of 15 gives more resolution, but then it can slow down the control loop
    capSense++;
  }
 
  digitalWrite(capSensePin, 0);    // To prepare for next measurement, we write a zero back to capSensePin
  pinMode(capSensePin, OUTPUT);    // and set it as an output.
  
  // The sensed quantity is then accumulated into the low-pass filter.
  capSenseLPF += capSense;
  
  return capSenseLPF;
}





// Wait for input data on the Arduino serial input.  If no serial input arrives for many iterations,
// assume that the host program on the laptop has been quit, so disable the the force while waiting.
// (Otherwise, the device can get stuck exerting a large force when quitting the host application.)
void waitForSerialInput(void){
  unsigned int waitSerial = 0;
  while (Serial.available() == 0) {
    waitSerial++;
    if (waitSerial == 65000) {
      // Set lowpass enable filter state variable to zero
      forceAEnableLPF = 0;
      forceBEnableLPF = 0;
      // Set motor forces to zero
      setPWM(PWMpinA, dirPinA, 0, 0, 0);
      setPWM(PWMpinB, dirPinB, 0, 0, 0);
    }
  }
}




// The main loop runs over and over.
void loop()
{
  // Variable definitions
  int tmp, unsignedForceA, unsignedForceB, signedForceA, signedForceB, potValueA, potValueB;
  int analog1 = 0, analog2 = 0, serialIn = 0;
  long byteCounter=10;
  
  
  // Read in packets until no packets are left waiting at the serial input
  
  while (1) {
    // First set dummy value for serialIn and wait until we receive the next sentinel
    serialIn = 1000;
    while (serialIn != 127) {
      // First wait until serial input data is available
      waitForSerialInput();

      // Then read in the next byte from serial
      serialIn = Serial.read();
    }
  
    // Now we can read the rest of the packet
    // For each byte, wait until it is available, and then do something with it.  
    // BYTE 1 
    waitForSerialInput();
    unsignedForceA = Serial.read();
    // BYTE 2 
    waitForSerialInput();
    unsignedForceB = Serial.read();
  
    // If no more serial data are available, then we are done read in serial data until next loop iteration.
    if (Serial.available() == 0)
      break;
  }
  
  

  // Write the forces to the motors
  signedForceA = setPWM(PWMpinA, dirPinA, unsignedForceA, forceAEnableLPF, BITSTOSHIFTTORQUE);
  signedForceB = setPWM(PWMpinB, dirPinB, unsignedForceB, forceBEnableLPF, BITSTOSHIFTTORQUE);

  
  capSenseLPFA = capSenseAndFilter(capSenseLPFA, capSensePinA);     // Takes 175 microseconds
  capSenseLPFB = capSenseAndFilter(capSenseLPFB, capSensePinB);     // Takes 175 microseconds
 
  
  analog2 = analogReadAveraging(currentPinB, 4, 2);    // This takes about 75 microseconds
  analog2 = analog2 >> 2;    // For convenience, make the result fit into 8 bits instead of the ADC default 10 bits
  analog1 = analogReadAveraging(currentPinA, 4, 2);    // This takes about 75 microseconds
  analog1 = analog1 >> 2;    // For convenience, make the result fit into 8 bits instead of the ADC default 10 bits
  // Alternatively and for debugging of the heat estimate and force enable filter, send these values instead.
  //analog1 = heatA >> 10;
  //analog2 = forceAEnableLPF;

     

  potValueB = (encoder1Pos >> BITSTOSHIFTANGLESENSING);
  if (potValueB > 254) {
    potValueB = 254;
  } else if (potValueB < 0) {
    potValueB = 0;
  }


  potValueA = (encoder0Pos >> BITSTOSHIFTANGLESENSING);
  if (potValueA > 254) {
    potValueA = 254;
  } else if (potValueA < 0) {
    potValueA = 0;
  }

  
  // Send data to laptop over serial connection -- this should go very fast on the Arduino Micro or Leonardo, but it takes 0.875 ms total on the Arduino Nano
  Serial.write(255);  // Write sentinel character to indicate beginning of packet
  // Then send data, one byte at a time, where each byte is clipped so that it cannot be equal to 255, which would cause confusion with the sentinel.
  SerialWriteNo255(potValueA);
  SerialWriteNo255(potValueB);
  SerialWriteNo255(analog1);
  SerialWriteNo255(analog2);
  SerialWriteNo255(capSenseLPFA);
  SerialWriteNo255(capSenseLPFB);
  Serial.flush();  // Make data available as soon as possible over serial
  
  
  
  
  // To update the heat estimate for the motors, we multiply the low pass filter state variable by 16383/16384,
  // and then we add signedForceA / 32.
  // NOTE: This is a one-pole lowpass filter with a pole at 16383/16384.
  heatA = heatA * (long)16383;
  heatA = heatA >> 14;
  heatA = heatA + (signedForceA >> 5);
  heatB = heatB * (long)16383;
  heatB = heatB >> 14;
  heatB = heatB + (signedForceA >> 5);
  
  
  // To update the force-enabling lowpass filteres, we multiply the low pass filter state variable by 31/32,
  // and then we add in 5 times a logic variable, which will either be 0 or 1.  It will only be 1 if
  //  * the potentiometer is not too far to the left (i.e. we must have potValue > 4)
  //  * the potentiometer is not too far to the right (i.e. we must have potValue < 251)
  //  * the heat variable is not too large to hopefully prevent the device from overheating due to misusage (i.e. heat/1024 < 40)
  //  * and the user is touching the fader (i.e. capSenseLPF > 30)
  forceAEnableLPF = forceAEnableLPF * 31;
  forceAEnableLPF = forceAEnableLPF >> 5;
  //forceAEnableLPF = forceAEnableLPF + 5*((potValueA < 251) && (potValueA > 4) && ((heatA >> 10) < 40) && (capSenseLPFA > 25));  // If having difficulty with capacitive sensing not being sensitive enough, try changing threshold here to something more like 20 instead of 25 or 30
  forceAEnableLPF = forceAEnableLPF + 5*((1) && (1) && ((heatA >> 10) < 40) && (capSenseLPFA > 25));  // If having difficulty with capacitive sensing not being sensitive enough, try changing threshold here to something more like 20 instead of 25 or 3
  
  forceBEnableLPF = forceBEnableLPF * 31;
  forceBEnableLPF = forceBEnableLPF >> 5;
  forceBEnableLPF = forceBEnableLPF + 5*((potValueB < 251) && (potValueB > 4) && ((heatB >> 10) < 40) && (capSenseLPFB > 25));  // If having difficulty with capacitive sensing not being sensitive enough, try changing threshold here to something more like 20 instead of 25 or 30
}

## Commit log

2012-07-12 Put the files online for the first time.
    In the later releases, I will sort the files better to make it more clear which parts are supported and which parts are not.
    [Parts.xlsx]
2012-10-04 Changes to v1.0 include - cleaned up the code and made it more presentable - made sure that all of the 1-channel versions of the code were compatible - made sure that all of the 1-channel versions of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
    [Arduino Nano2.brd, Arduino Nano2.sch, Parts List.xlsx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]
2013-06-04 Basically reorganized and reuploaded the entire repository with support for the FireFader.
    [Arduino Nano2.brd, Arduino Nano2.sch, Parts List.xlsx]
2014-11-04 Rotary device
2014-11-05 Added an IIR lowpass filter to the pot on the fader to reduce the motor noise.
    [detentsandmore.ino]
2015-10-05 Adding support for Bill Verplanks device
2016-07-01 Added firmware for version with two motors attached

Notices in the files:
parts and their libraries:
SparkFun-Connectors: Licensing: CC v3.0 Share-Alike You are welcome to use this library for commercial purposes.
